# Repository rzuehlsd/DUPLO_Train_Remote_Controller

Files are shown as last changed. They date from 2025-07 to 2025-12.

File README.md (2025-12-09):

# DUPLO Train Remote Controller System

**A event-driven train remote control system for LEGO DUPLO, built on ESP32, FreeRTOS, and Bluetooth Low Energy (BLE).**

Copyright (c) 2022-2025 Ralf Zühlsdorff

This project is licensed under the terms of the MIT License. See the License section below for details.

----
## Table of Contents

- [DUPLO Train Remote Controller System](#duplo-train-remote-controller-system)
  - [Table of Contents](#table-of-contents)
  - [Project Overview](#project-overview)
  - [User Interface](#user-interface)
    - [Quick Start: Connecting a DUPLO Train](#quick-start-connecting-a-duplo-train)
    - [Button \& Encoder Actions](#button--encoder-actions)
    - [Optical Feedback (Controller RGB LED)](#optical-feedback-controller-rgb-led)
    - [Implemented Sensor Callbacks](#implemented-sensor-callbacks)
    - [Auto-Sleep \& Wake-Up](#auto-sleep--wake-up)
  - [Architecture Overview](#architecture-overview)
    - [Dual-Core Strategy](#dual-core-strategy)
    - [Future Improvements](#future-improvements)
  - [System Architecture](#system-architecture)
    - [Multi-Task Processing with Bidirectional Communication](#multi-task-processing-with-bidirectional-communication)
    - [Three-Layer Architecture](#three-layer-architecture)
    - [duploHub.init() Bootstrapping Flow](#duplohubinit-bootstrapping-flow)
  - [Features](#features)
  - [Hardware Requirements](#hardware-requirements)
    - [Primary Hardware](#primary-hardware)
    - [Supported LEGO Hardware](#supported-lego-hardware)
    - [Technical Specifications](#technical-specifications)
  - [Hardware Design](#hardware-design)
  - [Software Dependencies](#software-dependencies)
    - [Platform](#platform)
    - [Libraries](#libraries)
    - [Library Versions](#library-versions)
  - [Installation](#installation)
    - [1. Environment Setup](#1-environment-setup)
    - [2. Project Build \& Upload](#2-project-build--upload)
    - [3. Hardware Setup](#3-hardware-setup)
  - [Usage](#usage)
    - [Basic Operation](#basic-operation)
    - [Expected Serial Debug Output](#expected-serial-debug-output)
  - [API Reference](#api-reference)
    - [DuploHub Class](#duplohub-class)
      - [Connection Management](#connection-management)
      - [Control Methods (Thread-Safe)](#control-methods-thread-safe)
      - [Information Methods](#information-methods)
      - [Event Callbacks](#event-callbacks)
    - [DuploHubExtended Class (Sensor Support)](#duplohubextended-class-sensor-support)
      - [Sensor Callbacks](#sensor-callbacks)
      - [Sensor Activation (Thread-Safe)](#sensor-activation-thread-safe)
      - [Example Usage](#example-usage)
    - [Available Colors](#available-colors)
    - [Motor Speed Range](#motor-speed-range)
  - [System Monitoring](#system-monitoring)
    - [Status Information](#status-information)
    - [Log Message Prefixes](#log-message-prefixes)
  - [Troubleshooting](#troubleshooting)
    - [Common Issues \& Solutions](#common-issues--solutions)
      - [Connection Problems](#connection-problems)
      - [Task Failures](#task-failures)
      - [Command Delays](#command-delays)
    - [Debug Mode](#debug-mode)
  - [Development](#development)
    - [Project Structure](#project-structure)
    - [Adding New Features](#adding-new-features)
      - [New Train Commands](#new-train-commands)
      - [New Hub Types](#new-hub-types)
    - [Code Style Guidelines](#code-style-guidelines)
  - [Contributing](#contributing)
    - [Development Process](#development-process)
    - [Testing Checklist](#testing-checklist)
  - [Links](#links)
  - [License](#license)
  - [Acknowledgments](#acknowledgments)

---

## Project Overview

This project implements a robust, multi-layered, event-driven train controller for LEGO DUPLO trains. 

The system not only covers the firmware to controll the DUPLO train but also the required hardware and the OpenSCAD files for the case of the handheld controller.

I used a Tenstar Super Mini ESP32-S3 FH4R2 controller (yes, it is totally overkill for this application) because it provides onboard functionality as a RGB LED (used for user feedback) and a charging controller for a 3.7V Lithium battery. This onboard functionality reduced the required external components for the handheld controller to only 6 SMD switches, a rotary encoder and a few SMD resistors plus 1 capacitor.

The firmware builds on top of the open-source [Legoino](https://github.com/corneliusmunz/legoino) library created by Cornelius Munz, reusing its Powered Up protocol support while adding a hardened hardware abstraction tailored to ESP32 dual-core devices. Using both cores to implement the app signifficantly increased the overall reliability.

Key pillars of the solution include:

- **ESP32 dual-core architecture** (FreeRTOS): BLE communication runs independently from application logic for deterministic responsiveness.
- **Legoino-powered protocol stack**: Proven LEGO Powered Up discovery, device activation, and message parsing.
- **Thread-safe command and sensor queues**: Bidirectional, non-blocking communication between BLE and main application tasks.
- **Automatic connection management**: Self-healing BLE connections with exponential backoff recovery.
- **Enhanced logging and monitoring**: Real-time status, error, and performance reporting.
- **Deep Sleep and Wakeup**: In case no user interactions have been detected for more than 5 minutes the device goes to sleep and can be waked up by pressing the encoder button.

The high-level structure is summarised below; a deeper dive is available in [ARCHITECTURE.md](ARCHITECTURE.md).

## User Interface

THe handheld DUPLO train controller has 6 switches and a rotary encoder to send BLE commands to the DUPLO train hub. User feedback is provided through the onboard RGB LED of the ESP32-S3 controller.

### Quick Start: Connecting a DUPLO Train
- Power on the controller (ESP32) and the DUPLO Train Hub. 
- The DUPLO train will show a **white** blinking front light.
- The RGB LED of the controller turns to **yellow**.
- The controller immediately begins scanning for an active duplo train.
- Once internal initializatioon of the controller is completed the RBB LED turns to **green**. 
- If connected the DUPLO train will show a solid **blue** front light.
- After DUPLO train has connected, the controller’s RGB status LED turns to *blue** and blinks 3 times to confirm link.
- If no hub is found, the status LED pulses **orange** every few seconds to prompt you to power cycle or move the train closer.

### Button & Encoder Actions
- **Rotary encoder (turn):** Proportionally ramps the train motor between full reverse, neutral, and full forward with a tactile centre detent to simplify stops.
- **Rotary encoder (press):** Wakes the controller from deep sleep.
- **Record button:** Starts or stops capture of the current driving session, including speed, light, and sound changes for later replay.
- **Play button:** Replays the most recently recorded session, mirroring the captured timing for motor, LED, and audio cues. Press again to stop replay.
- **Stop button:** Issues an immediate emergency stop, cutting motor power and triggering the associated brake feedback sequence. To start normal operation the stop button **HAS TO BE PRESSED AGAIN**!
- **Light button:** Cycles through the preset DUPLO hub LED colours so the train can be themed without using a screen or app.
- **Sound button:** Steps through the curated horn, brake, and station audio effects for interactive play.
- **Water button:** Runs the refill routine, pausing the train, playing the refill sound, and resuming at the previous throttle setting.

### Optical Feedback (Controller RGB LED)
- **Blue (pulsing 5 times):** Connection to a DUPLO hub establish and ready for commands.
- **Red (slow blinking):** Recording action sequence.
- **Yellow (slow blinking):** Replaying action sequence.
- **Red (steady):** Emergency stop engaged. Goes off if button is engaged again
- **Red (fast pulses 5 times):** Signals low voltage of DUPLO train battery every 300 seconds

### Implemented Sensor Callbacks

The controller provides callback implementations for speed, voltage and color sensor events. While the speed sensor is currently not used, the voltage sensor gives warning feedback, if battery voltage of DUPLO Train drops below 5V.

The color sensor is used to detect the color bricks provided with the DUPLO train set to trigger preprogrammed actions. The detection of the correct colors is very tricky as it depends on the reflection of the color bricks. So expect some wrong colors to be detected. As we overwrite the preprogrammed actions here is a short description of the implemented actions:

- **RED** triggers a stop of the train with brake sound and red headlights
- **YELLOW** triggers departure of the train with yellow blinking headlights and horn sound
- **BLUE** triggers water refill action with blinking blue headlight, stop of train, water refill sound and departure of train with last defined speed

Currently all other colored bricks just set the headlight to the respective color.

### Auto-Sleep & Wake-Up
- After **5 minutes** without button presses or encoder turns, the controller enters deep sleep to save power; the status LED fades out to indicate standby.
- To reactivate, press the rotary encoder once to start initialization and connection cycle again

---
## Architecture Overview

The firmware is organised into three cooperating layers:

1. **Application Layer (`TrainController`)** – orchestrates user input, status LED feedback, replay/record logic, and system health checks.
2. **Hardware Abstraction Layer (`DuploHub`)** – maintains thread-safe command/response queues, sensors, and lifecycle management for the BLE task.
3. **Protocol Layer (`myLegoHub`/Legoino)** – bridges to the LEGO Powered Up protocol, handling device discovery and low-level message encoding.

These layers communicate exclusively through FreeRTOS queues and callbacks, which allows the BLE task and user interface to stay decoupled. The full architectural description, sequence diagrams, and performance considerations are documented in [ARCHITECTURE.md](ARCHITECTURE.md).

### Dual-Core Strategy

The ESP32’s two cores are used deliberately to isolate time-critical communication from user-driven workloads:

- **Core 0** is dedicated to the BLE stack (NimBLE) and the `DuploHub` task, guaranteeing consistent connection upkeep and sensor polling under tight timing constraints.
- **Core 1** runs the Arduino loop (`TrainController`), handling rotary encoder updates, button ladders, response queue processing, and visual/audible feedback without blocking the BLE stack.

This separation keeps latency predictable—even when the UI is busy—and prevents sensor interrupts or sound/LED routines from starving the communication pipeline.

### Future Improvements

- Function to pair with train (store ID and use when connecting)

---
## System Architecture

### Multi-Task Processing with Bidirectional Communication

```mermaid
graph LR
   MainTask["<b>Core 1 – Main Task</b><br/>• Application logic<br/>• User interface<br/>• Status display<br/>• Demo logic<br/>• Sensor processing<br/>• Event callbacks"]

   BleTask["<b>Core 0 – BLE Task</b><br/>• BLE operations<br/>• Hub connection<br/>• Motor commands<br/>• LED control<br/>• Sensor setup<br/>• Data parsing"]

   MainTask --> |CommandQueue| BleTask

   BleTask --> |SensorQueue| MainTask

   classDef queueStyle fill:#f2f2f2,stroke:#333,stroke-width:1px
   class CommandQueue,SensorQueue queueStyle
```

### Three-Layer Architecture

```mermaid
graph LR
   Layer1["<b>Layer 1: Application Layer</b><br/>• Train demo sequence &amp; state management<br/>• User interface &amp; status monitoring<br/>• High-level control logic<br/>• Connection event handling<br/>• Sensor data processing &amp; callbacks"]

   Layer2["<b>Layer 2: Hardware Abstraction</b><br/>• Thread-safe command queue<br/>• Bidirectional FreeRTOS queues<br/>• Multi-task management (dual-core ESP32)<br/>• Connection state management<br/>• Automatic recovery &amp; error handling<br/>• Sensor routing &amp; callback management"]

   Layer3["<b>Layer 3: Protocol Layer</b><br/>• LEGO Powered Up protocol<br/>• Bluetooth LE communication<br/>• Device discovery &amp; connection<br/>• Motor &amp; LED control commands<br/>• Sensor data parsing &amp; callbacks"]

   Layer1 -->|Clean API + sensor callbacks| Layer2
   Layer2 -->|Protocol interface + sensor integration| Layer3
```

### duploHub.init() Bootstrapping Flow

The following sequence diagram visualizes how the application brings up the BLE infrastructure when `duploHub.init()` is called from `TrainController::setup()`.

```mermaid
sequenceDiagram
   participant TC as TrainController::setup
   participant DH as DuploHub
   participant RTOS as FreeRTOS Scheduler
   participant BLE as BLE Task (Core 0)
   participant Lpf2 as Lpf2Hub

   TC->>DH: init()
   activate DH
   DH->>DH: initFreeRTOS()
   DH->>RTOS: xTaskCreatePinnedToCore(bleTaskWrapper)
   RTOS-->>DH: Task handle
   deactivate DH
   DH-->>TC: return

   RTOS->>BLE: schedule bleTaskWrapper(this)
   activate BLE
   BLE->>DH: bleTaskFunction()
   loop continuous loop
      BLE->>DH: updateBLE()
      alt Hub disconnected
         DH->>Lpf2: hub.init()
      else Hub connecting
         DH->>Lpf2: connectHub()
      end
      opt Connection state change
         DH-->>TC: onConnectedCallback()/onDisconnectedCallback()
      end
      BLE->>DH: processCommandQueue()
      DH->>Lpf2: Execute queued command
      BLE->>BLE: vTaskDelay(50 ms)
   end
```

---

## Features

- **Multi-Task BLE Management**: BLE operations run on a dedicated core, never blocking the main application.
- **Automatic Connection & Recovery**: Discovers, connects, and reconnects to DUPLO train hubs automatically.
- **Thread-Safe Commands**: Queue-based command system prevents race conditions.
- **Real-Time Control**: Low-latency motor speed and LED color control driven by rotary encoder input.
- **Sensor Integration**: Color, speed, and voltage sensors with callback support and queue isolation.
- **Color Stability Filtering**: Timer-based debounce suppresses transient color readings before they reach the UI.
- **Command Recording & Replay**: Capture user sessions and play them back with preserved timing.
- **Professional Logging**: Detailed, component-specific log messages and system status monitoring.
- **Idle Power Management**: Automatic deep sleep after configurable idle periods, resume via encoder button.
- **Resource Management**: Proper FreeRTOS object lifecycle management.
- **Input Abstraction**: ADC button ladder and rotary encoder handlers with debounced callbacks.
- **Demo Mode**: Non-blocking demo sequence with visual feedback and safety features.

---

## Hardware Requirements

### Primary Hardware

- **ESP32 Development Board ESP32-S3 Super Mini** (see link below)
    I use the Tenstar ESP32-S3 FH4R2 SuperMini which also includes cuircits to charge a 3.7V Lithium battery.
- **LEGO DUPLO Train Hub** with motor connected to Port A
- **USB Type C Cable** for programming and power

### Supported LEGO Hardware

- DUPLO Train Hub (Hub Type: `DUPLO_TRAIN_HUB`)
- DUPLO Train Motors (connected to Port A)
- Compatible with other Powered Up hubs (with minor modifications)

### Technical Specifications

- **Microcontroller**: ESP32 (dual-core, 240MHz)
- **Memory**: 520KB SRAM, 4MB Flash minimum
- **Connectivity**: Bluetooth 4.2 LE
- **Operating Voltage**: 3.3V
- **Power Consumption**: ~130mA during active BLE operation

---

## Hardware Design

The following images show the KiCAD 3d view of the controller pcb and the OpenSCAD view of the controller case. To design the controller case the MachineBlocks library from pks5 (https://github.com/pks5/machineblocks) has been used.

<p align="center">
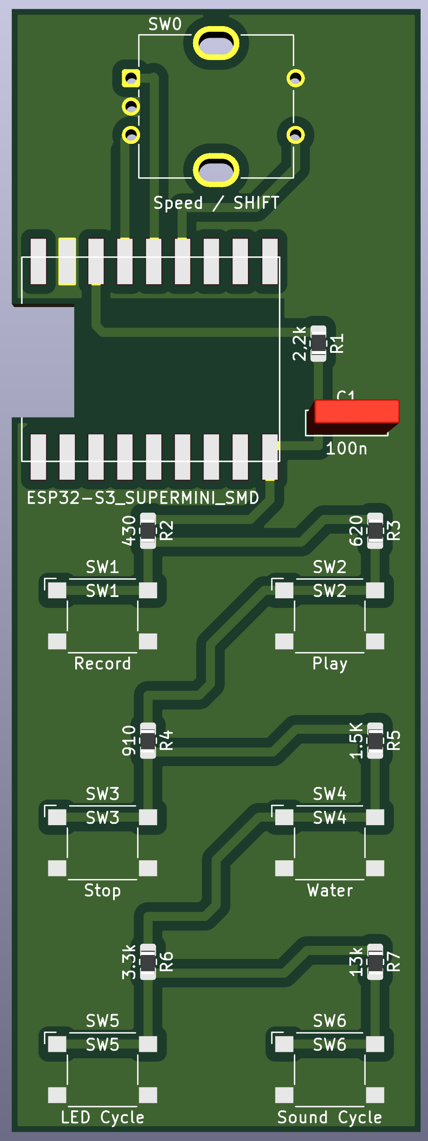
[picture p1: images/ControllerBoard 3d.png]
Controller board 3D render
    
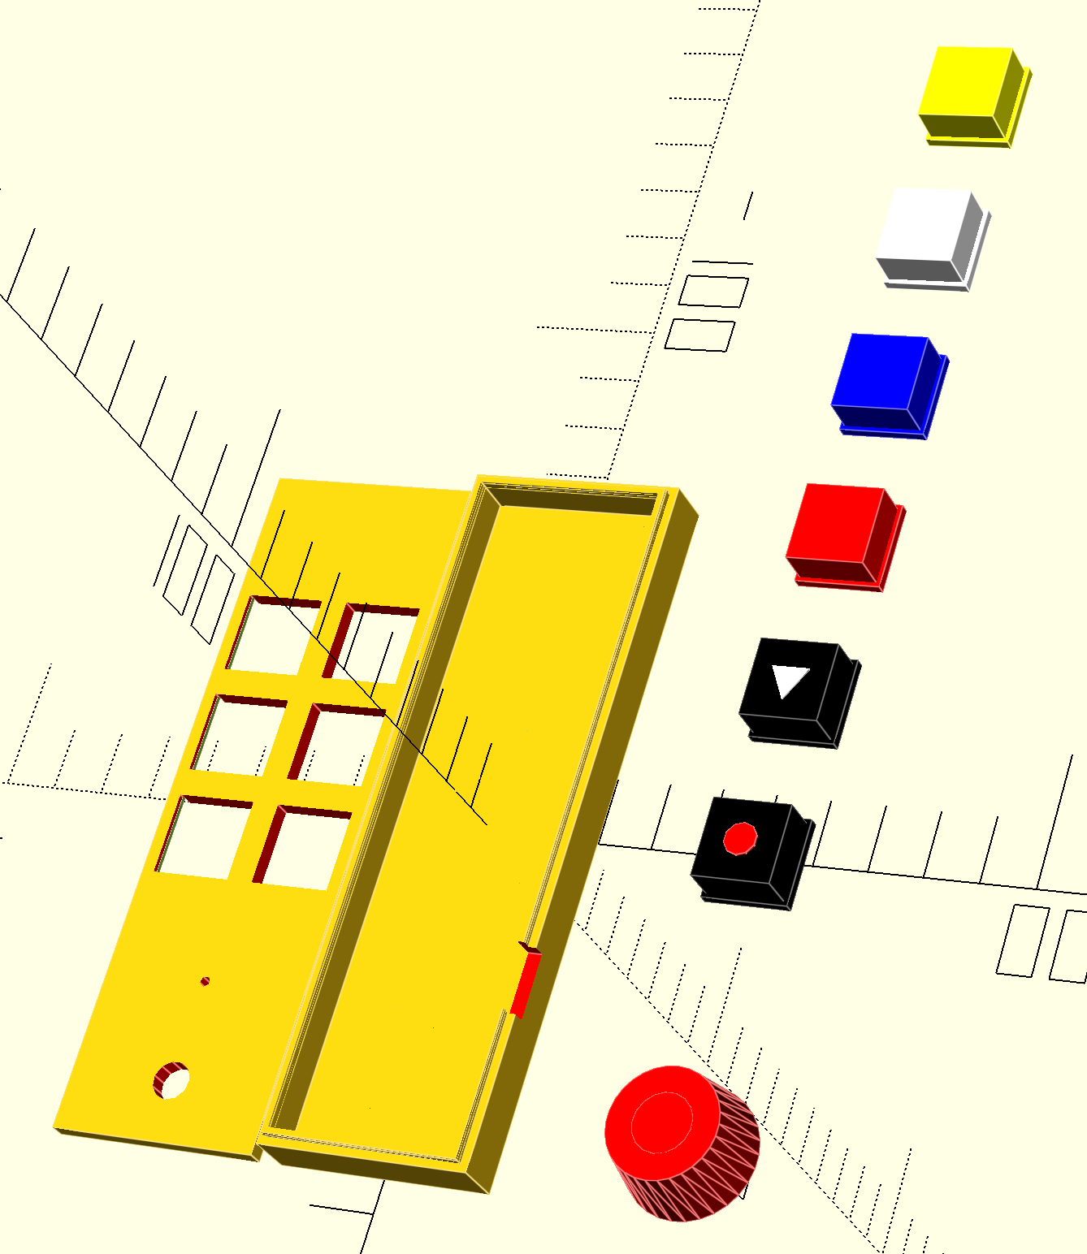
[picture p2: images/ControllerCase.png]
Controller case
    
</p>

- A dedicated ESP32-S3 carrier board with battery management and button/encoder headers is captured in KiCad inside `hardware/DuploTrainController NG`.
- A matching printable enclosure is modelled in OpenSCAD in `hardware/Case`, which also embeds the MachineBlocks library to speed up iteration on DUPLO-sized parts.

See [hardware/Hardware.md](hardware/Hardware.md) for a detailed description of the custom controller hardware.

## Software Dependencies

### Platform
- **PlatformIO**: Development platform
- **ESP32 Arduino Framework**: Core ESP32 support
- **FreeRTOS**: Real-time operating system (included with ESP32)

### Libraries

- **Legoino**: LEGO Powered Up protocol implementation by Cornelius Munz
- **NimBLE-Arduino**: Bluetooth Low Energy stack

All other libs used are provided as source in include and src dir.

### Library Versions

```ini
[env:esp32dev]
platform = espressif32
board = esp32dev
framework = arduino
lib_deps = 
    legoino/Legoino
    h2zero/NimBLE-Arduino
```

---

## Installation

Th development of this code has been done with MS Studio Code and PlatformIO.

### 1. Environment Setup

```bash
# Install PlatformIO CLI
pip install platformio

# Clone the repository
git clone <repository-url>
cd DuploTrain
```

### 2. Project Build & Upload

```bash
# Build the project
pio run

# Upload to ESP32
pio run --target upload

# Open serial monitor
pio device monitor
```

### 3. Hardware Setup

1. Connect ESP32 to computer via USB
2. Power on your DUPLO train hub
3. Ensure motor is connected to Port A of the hub
4. Upload and run the code

---

## Usage

### Basic Operation

1. **Startup**: System automatically starts and begins scanning for DUPLO hubs
2. **Connection**: When hub is found, automatic connection is established
3. **Demo**: Once connected, the demo sequence begins automatically
4. **Monitoring**: Status information is displayed every 10 seconds

### Expected Serial Debug Output

```text
TrainController: Starting up...
DuploHub: FreeRTOS objects initialized
DuploHub: BLE task started successfully
TrainController: Ready - BLE task running, waiting for hub connection...
BLE Task: Started successfully
BLE Task: Attempting initial connection to hub...
BLE Task: Connected to HUB
TrainController: Hub connected - initializing train demo!
TrainController: Starting train demo sequence...
TrainController Status - BLE Task: Running, Hub Connected: Yes, Demo Active: Yes
```

---

## API Reference

### DuploHub Class

#### Connection Management

```cpp
void startBLETask();                    // Start background BLE task
void stopBLETask();                     // Stop background BLE task
bool isConnected();                     // Check connection status (thread-safe)
bool isConnecting();                    // Check if connecting (thread-safe)
bool isDisconnected();                  // Check if disconnected (thread-safe)
bool isBLETaskRunning();                // Check BLE task status
```

#### Control Methods (Thread-Safe)

```cpp
void setMotorSpeed(int speed);          // Set motor speed (-100 to 100)
void stopMotor();                       // Stop motor immediately
void setLedColor(Color color);          // Set hub LED color
void setHubName(const char* name);      // Set hub name
```

#### Information Methods

```cpp
std::string getHubAddress();            // Get hub BLE address
std::string getHubName();               // Get hub name
byte getMotorPort();                    // Get configured motor port
void setMotorPort(byte port);           // Set motor port
```

#### Event Callbacks

```cpp
void setOnConnectedCallback(ConnectionCallback callback);     // Hub connected event
void setOnDisconnectedCallback(ConnectionCallback callback);  // Hub disconnected event
```

### DuploHubExtended Class (Sensor Support)

#### Sensor Callbacks

```cpp
typedef void (*ColorSensorCallback)(int color, byte port);
typedef void (*DistanceSensorCallback)(int distance, byte port);
typedef void (*ButtonCallback)(ButtonState state);

void setOnColorSensorCallback(ColorSensorCallback callback);      // Color sensor events
void setOnDistanceSensorCallback(DistanceSensorCallback callback);  // Distance sensor events
void setOnButtonCallback(ButtonCallback callback);                 // Button press events
```

#### Sensor Activation (Thread-Safe)

```cpp
void activateColorSensor(byte port);      // Activate color sensor on specified port
void activateDistanceSensor(byte port);   // Activate distance sensor on specified port
void activateButton();                    // Activate hub button monitoring
```

#### Example Usage

```cpp
// Color-based speed control
void onColorDetected(int color, byte port) {
    if (color == (byte)Color::RED) {
        duploHub.stopMotor();           // Emergency stop
    } else if (color == (byte)Color::GREEN) {
        duploHub.setMotorSpeed(50);     // Fast speed
    }
    duploHub.setLedColor((Color)color); // Match LED to detected color
}

// Setup
DuploHubExtended duploHub;
duploHub.setOnColorSensorCallback(onColorDetected);
duploHub.activateColorSensor((byte)PoweredUpHubPort::B);
```

### Available Colors

```cpp
BLACK, PINK, PURPLE, BLUE, LIGHTBLUE, CYAN, GREEN, YELLOW, ORANGE, RED, WHITE
```

### Motor Speed Range

- **Range**: -100 to 100
- **Positive**: Forward direction
- **Negative**: Backward direction
- **Zero**: Stop (equivalent to `stopMotor()`)

---

## System Monitoring

- **BLE Task**: Runs on Core 0, Priority 2
- **Main Loop**: Runs on Core 1, Priority 1
- **Connection Checks**: Every 1 second
- **Command Processing**: Every 50ms
- **Status Updates**: Every 10 seconds

### Status Information

The system provides comprehensive monitoring through serial output:

```text
TrainController Status - BLE Task: Running, Hub Connected: Yes, Demo Active: Yes
```

### Log Message Prefixes

- **`TrainController:`** - Main application messages
- **`BLE Task:`** - Background BLE task messages  
- **`DuploHub:`** - Hardware abstraction layer messages
- **`ERROR:`** - Critical system errors
- **`WARNING:`** - Non-critical issues

---

## Troubleshooting

### Common Issues & Solutions

#### Connection Problems
- Ensure DUPLO hub is powered on and in pairing mode
- Check if hub is already connected to another device
- Reset hub by holding button for 10 seconds
- Move ESP32 closer to hub (within 5 meters)

#### Task Failures
- Check available heap memory: `ESP.getFreeHeap()`
- Reduce other running tasks
- Increase stack size in `startBLETask()`

#### Command Delays
- Check command queue status
- Verify BLE connection stability
- Reduce command frequency in application

### Debug Mode

Enable detailed debugging by adding to `platformio.ini`:

```ini
build_flags = -DCORE_DEBUG_LEVEL=4
monitor_filters = esp32_exception_decoder
```

---

## Development

### Project Structure

```text
DuploTrain NG/
├── hardware/
│   ├── Case/
│   │   ├── Controller.scad
│   │   ├── MachineBlocks/
│   │   └── lib/
│   ├── DuploTrainController NG/
│   │   ├── DuploTrainController NG.kicad_pcb
│   │   ├── DuploTrainController NG.kicad_sch
│   │   ├── DuploTrainController NG.kicad_pro
│   │   ├── DuploTrainController NG.kicad_prl
│   │   ├── DuploTrainController NG.kicad_pcb.zip
│   │   ├── 5 Buttons an ADC.xlsx
│   │   └── Gerber/
│   └── README.md
├── include/
│   ├── ADCButton.h
│   ├── DuploHub.h
│   ├── StatusLED.h
│   ├── SystemMemory.h
│   ├── debug.h
│   └── myLegoHub.h
├── lib/
│   ├── Legoino/
│   └── NimBLE-Arduino/
├── src/
│   ├── ADCButton.cpp
│   ├── DuploHub.cpp
│   ├── StatusLED.cpp
│   ├── SytemMemory.cpp
│   ├── TrainController.cpp
│   ├── debug.cpp
│   └── myLegoHub.cpp
├── test/
│   ├── DuploTrainTests.cpp
│   ├── DuploTrainTests.h
│   └── README.md
├── ARCHITECTURE.md
├── CHANGELOG.md
├── platformio.ini
└── README.md
```

### Adding New Features

#### New Train Commands
1. Add command type to `CommandType` enum in `DuploHub.h`
2. Add command data structure to `HubCommand` union
3. Implement thread-safe method in `DuploHub` class
4. Add processing logic to `processCommandQueue()`

#### New Hub Types
1. Modify hub type detection in BLE scanning
2. Add hub-specific command handling
3. Update motor port configurations if needed

### Code Style Guidelines
- Use clear, descriptive variable names
- Add comprehensive comments for complex logic
- Follow Arduino coding standards
- Use thread-safe practices for shared data
- Include error handling for all operations

---

## Contributing

### Development Process
1. Fork the repository
2. Create feature branch (`git checkout -b feature/new-feature`)
3. Follow code style guidelines
4. Add comprehensive comments
5. Test thoroughly on hardware
6. Submit pull request with detailed description

### Testing Checklist
- [ ] Builds without warnings
- [ ] Connects to DUPLO hub successfully
- [ ] Motor control works in both directions
- [ ] LED colors change correctly
- [ ] Reconnection works after power cycle
- [ ] No memory leaks during long operation
- [ ] Task monitoring shows healthy system

---

## Links

- [ESP32 Super Mini](https://de.aliexpress.com/item/1005010463397231.html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)
- [Lithium Battery 3.7V](https://de.aliexpress.com/item/1005004378108918.html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,scm-url:1007.14452.478275.0,pvid:03756532-275c-4ab9-bd8a-2053af674cb4,tpp_buckets:668%232846%238108%231977&pdp_ext_f=%7B%22order%22%3A%2247%22%2C%22eval%22%3A%221%22%2C%22sceneId%22%3A%2230050%22%2C%22fromPage%22%3A%22recommend%22%7D&pdp_npi=6%40dis%21EUR%215.68%214.09%21%21%216.46%214.65%21%4021038e6617651853991155852e878e%2112000028967861661%21rec%21DE%216288981052%21X%211%210%21n_tag%3A-29919%3Bd%3A6804e1a2%3Bm03_new_user%3A-29895&utparam-url=scene%3ApcDetailTopMoreOtherSeller%7Cquery_from%3A%7Cx_object_id%3A1005004378108918%7C_p_origin_prod%3A&search_p4p_id=202512080116391515856091447492685637_4)
- [MachineBlocks](https://github.com/pks5/machineblocks)
---

## License

MIT License

Permission is hereby granted, free of charge, to any person obtaining a copy
of this software and associated documentation files (the "Software"), to deal
in the Software without restriction, including without limitation the rights
to use, copy, modify, merge, publish, distribute, sublicense, and/or sell
copies of the Software, and to permit persons to whom the Software is
furnished to do so, subject to the following conditions:

The above copyright notice and this permission notice shall be included in all
copies or substantial portions of the Software.

THE SOFTWARE IS PROVIDED "AS IS", WITHOUT WARRANTY OF ANY KIND, EXPRESS OR
IMPLIED, INCLUDING BUT NOT LIMITED TO THE WARRANTIES OF MERCHANTABILITY,
FITNESS FOR A PARTICULAR PURPOSE AND NONINFRINGEMENT. IN NO EVENT SHALL THE
AUTHORS OR COPYRIGHT HOLDERS BE LIABLE FOR ANY CLAIM, DAMAGES OR OTHER
LIABILITY, WHETHER IN AN ACTION OF CONTRACT, TORT OR OTHERWISE, ARISING FROM,
OUT OF OR IN CONNECTION WITH THE SOFTWARE OR THE USE OR OTHER DEALINGS IN THE
SOFTWARE.

---

## Acknowledgments

- **Cornelius Munz** - Legoino library creator
- **LEGO Group** - DUPLO and Powered Up hardware
- **Espressif** - ESP32 platform
- **Arduino Community** - Framework and libraries

---

**Version:** 2.0.0  
**Last Updated:** July 2025  
**Compatibility:** ESP32, Arduino Framework, PlatformIO

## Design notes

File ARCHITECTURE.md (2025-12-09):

# Technical Architecture Document

**Author:** Ralf Zühlsdorff  
**Copyright:** (c) 2025 Ralf Zühlsdorff  
**License:** MIT License

---

## System Overview

The DUPLO Train Controller implements a robust, modular, event-driven architecture for LEGO train control, optimized for ESP32 dual-core systems. It extends the [Legoino](https://github.com/JorgePe/legoino) library by Jorge Pereira, adding hardened FreeRTOS primitives, queue-based communication, and application-level automation tailored to ESP32 hardware capabilities. The design leverages thread-safe queues and static callback wrappers to ensure reliable BLE communication, real-time sensor feedback, and responsive user control.

Key runtime capabilities include:

- Dual-core scheduling that dedicates Core 0 to BLE and sensor handling while Core 1 processes user interaction and replay automation.
- A color stability timer that debounces rapid sensor transitions before events reach the UI layer.

## Multi-Task Architecture

```
ESP32 Core 0 (Protocol Core)        ESP32 Core 1 (Application Core)
├── BLE Stack (NimBLE)              ├── Arduino Main Loop
├── BLE Task (DuploHub)             ├── TrainController Logic
├── FreeRTOS Scheduler              ├── Demo State Machine
└── Hardware Interrupts             └── User Callbacks
```

| Task | Core | Priority | Stack Size | Timing |
|---|---|---|---|---|
| Arduino Loop | 1 | 1 | 8KB | Continuous |
| BLE Task | 0 | 2 | 4KB | 50ms cycle |
| Idle Tasks | Both | 0 | 1KB | As needed |
```cpp

class DuploHub {
private:
    SemaphoreHandle_t connectionMutex;    // Protects connection state
    QueueHandle_t commandQueue;           // Main → BLE task commands
    QueueHandle_t responseQueue;          // BLE task → Main responses/events
    TaskHandle_t bleTaskHandle;           // BLE task lifecycle
    volatile bool connectionState;        // Atomic state variables
    volatile bool connectingState;
};
```

### Critical Sections

```cpp

// Example: Thread-safe connection state access
bool DuploHub::isConnected() {
    if (connectionMutex != nullptr) {
        xSemaphoreTake(connectionMutex, portMAX_DELAY);
        bool state = connectionState;
        xSemaphoreGive(connectionMutex);
        return state;
    }
    return hub.isConnected(); // Fallback if mutex not initialized
}
```

### Command Queue Protocol

```cpp

// Command structure for inter-task communication
typedef struct {
    CommandType type;           // Command identifier
    union {
        struct { int speed; } motor;
        struct { Color color; } led;
        struct { char name[32]; } hubName;
        // ... other command types ...
    } data;
} HubCommand;

// Response structure for BLE → Main communication
typedef struct {
    ResponseType type;          // Response identifier (e.g., Detected_Color, Detected_Speed)
    union {
        struct { int detectedColor; } colorResponse;
        struct { int detectedSpeed; } speedResponse;
        struct { float detectedVoltage; } voltageResponse;
        // ... other response types ...
    } data;
} HubResponse;
```

## Memory Management

### Static Allocation Strategy
- **Command Queue**: 10 × `sizeof(HubCommand)` = ~320 bytes
- **Task Stacks**: BLE Task (4KB), Main Loop (8KB)
- **Synchronization Objects**: ~100 bytes total
- **String Buffers**: Fixed-size arrays for thread safety

### Heap Usage Optimization
- Minimal dynamic allocation
- String operations use stack buffers
- BLE operations handled by NimBLE stack
- No memory leaks in main application code

## Communication Flow

### Startup Sequence

```mermaid
sequenceDiagram
    participant App as TrainController
    participant Hub as DuploHub
    participant BLE as BLE Task
    participant LEGO as Lpf2Hub

    App->>Hub: Constructor (initFreeRTOS)
    Hub->>Hub: Create Mutex & Queue
    App->>Hub: startBLETask()
    Hub->>BLE: Create Task (Core 0)
    BLE->>LEGO: hub.init() - Start scanning
    LEGO-->>BLE: Device found callback
    BLE->>LEGO: hub.connectHub()
    BLE->>Hub: updateConnectionState(true)
    Hub->>App: onConnectedCallback()
```

### Command Execution Flow

```mermaid
sequenceDiagram
    participant App as TrainController
    participant Queue as Command Queue
    participant BLE as BLE Task
    participant LEGO as Lpf2Hub

    App->>Queue: setMotorSpeed(50)
    Queue-->>BLE: Command available
    BLE->>Queue: Dequeue command
    BLE->>LEGO: setBasicMotorSpeed(port, 50)
    LEGO-->>BLE: BLE transmission complete
```

## Error Handling Strategy

### Failure Recovery Mechanisms

1. **BLE Task Monitoring**: Main loop checks task health every 5 seconds
2. **Connection Recovery**: Automatic reconnection with exponential backoff
3. **Command Queue Overflow**: Non-blocking queue operations with warnings
4. **Resource Cleanup**: Proper destruction in destructors and error paths

### Error Categories

| Category | Handling | Recovery |
|---|---|---|
| BLE Connection Loss | Automatic retry | Background reconnection |
| Task Creation Failure | Error logging | Fallback to synchronous mode |
| Queue Full | Drop command + warning | Continue operation |
| Memory Allocation | Error logging | Graceful degradation |

## Performance Characteristics

### Latency Analysis

| Operation | Typical Latency | Maximum Latency |
|---|---|---|
| Motor Command | 50-100ms | 200ms |
| LED Command | 30-80ms | 150ms |
| Connection Detection | 1-3 seconds | 10 seconds |
| State Query | <1ms | 5ms (mutex wait) |

### Throughput Capabilities

- **Command Rate**: ~20 commands/second sustainable
- **BLE Bandwidth**: ~1KB/second LEGO protocol data
- **CPU Utilization**: ~15% Core 0, ~5% Core 1 during active operation

## Bidirectional Sensor Data Architecture

### Queue Model

The firmware relies on two FreeRTOS queues to decouple the BLE task from the application loop:

```mermaid
flowchart LR
    subgraph Core1["Main Loop (Core 1)"]
        TC["TrainController::loop<br/>• Rotary & buttons<br/>• processResponseQueue<br/>• record / replay"]
    end

    subgraph Core0["BLE Task (Core 0)"]
        BLE["DuploHub::bleTaskFunction<br/>• hub.connectHub()<br/>• processCommandQueue<br/>• static callbacks"]
    end

    CommandQueue["commandQueue<br/>(10 items)"]:::queue
    ResponseQueue["responseQueue<br/>(100 items)"]:::queue

    TC -->|commands| CommandQueue -->|dispatch| BLE
    BLE -->|responses| ResponseQueue -->|process| TC

    classDef queue fill:#f2f2f2,stroke:#555,stroke-width:1px;
```

- `commandQueue` carries `HubCommand` objects from the application to the BLE task (motor, sound, LED, sensor activation, name changes). Each command includes a timestamp so the recorder can normalise playback timing.
- `responseQueue` returns `HubResponse` objects (colour, speed, voltage updates) from the BLE task to the application. The queue depth of 100 entries absorbs bursts from the colour sensor while the UI performs other work.

### Color Stability Timer

Rapid color transitions generated by the DUPLO sensor are filtered by a one-shot `esp_timer` that fires after 250 ms of stability. The timer is created lazily by `ensureColorTimerInitialized()` and shared across callbacks via a `portMUX_TYPE` critical section. The timer callback:

1. Compares the pending colour against the last stable value.
2. Enqueues a `HubResponse` only when the reading truly changes.
3. Resets the pending colour so the next sensor event will re-arm the timer.

This approach lowers noise in the response queue without blocking the BLE task, and keeps user automation deterministic.

### Command & Event Flow

1. **Command path (Main → BLE)**
   ```cpp
   HubCommand cmd = {...};
   sendCommand(cmd, pdMS_TO_TICKS(100));   // TrainController → DuploHub
   // BLE task dequeues the command and forwards it via Legoino APIs
   ```

2. **Sensor path (BLE → Main)**
   ```cpp
   staticColorSensorCallback(...)  // BLE context
     ↳ ensureColorTimerInitialized()
     ↳ esp_timer_start_once()

   colorStabilityTimerCallback(...)
     ↳ HubResponse response{Detected_Color, ...};
     ↳ xQueueSend(responseQueue, ...);

   TrainController::processResponseQueue()
     ↳ switch(response.type) { ... detectedColorCb(...) ... }
   ```

3. **Record / Replay integration**
   - When recording is enabled, every outbound `HubCommand` is copied into `commandBuffer` together with its timestamp.
   - `replayCommands()` normalises timestamps and replays through `sendCommand()` while the main loop checks `getNextReplayCommand()` to maintain timing.

### Memory Usage Snapshot

| Queue | Direction | Capacity | Approx. item size | Purpose |
|---|---|---|---|---|
| `commandQueue` | Main → BLE | 10 items | ~48 B (`HubCommand`) | Motor, LED, sound, sensor activation, hub name |
| `responseQueue` | BLE → Main | 100 items | ~16 B (`HubResponse`) | Colour, speed, voltage notifications |

Additional shared resources include the connection mutex (~92 B), the BLE task stack (4 KB), and the colour stability timer (control block provided by ESP timer service).

### Extending `HubCommand` / `HubResponse`

New device capabilities can be exposed by adding enum values and union members in `include/DuploHub.h`. The queue infrastructure already supports arbitrary payloads as long as the structs remain POD types.

### Multiple Hub Support

Managing several train hubs simply requires instantiating multiple `DuploHub` objects—each one provisions its own command/response queues, timer handle, and BLE task instance.

## Debug and Monitoring Infrastructure

### Logging and Debugging

The system uses a mutex-protected debug logging macro (`DEBUG_LOG`) for thread-safe output from both main and BLE tasks. Logging levels can be adjusted for error, warning, info, and debug output.

### Runtime Statistics

System monitoring functions (e.g., `printMemoryInfo()`) are available to report free heap, BLE task stack usage, and queue status for debugging and performance analysis.

## Security Considerations

### BLE Security
- No pairing/bonding implemented (LEGO hubs don't require it)
- Connection based on service UUID matching
- Limited to LEGO protocol commands only

### Code Security
- No dynamic code execution
- Fixed-size buffers prevent overflows
- Input validation on all external data

## Documentation and Code Quality

All major classes and functions are documented using Doxygen-style comments, including parameter and return value descriptions. Each file includes author, copyright, and the full MIT license.

**Future Enhancement Opportunities:**

1. **Sensor Integration**: Support for LEGO speed sensor
2. **Multiple Trains**: Coordinate multiple train hubs, e.g. pinning controller to specific train

## Complete Sensor Processing Chain Analysis

This section provides a complete trace of how a sensor value (e.g., color detection) flows through all layers of the architecture, from physical hardware to application callback.

### **Layer 1: Physical Hardware → BLE Radio**
```
DUPLO Color Sensor Hardware
├── Detects color change (e.g., RED)
├── Generates sensor data packet
└── Transmits via BLE to ESP32
```
- **📍 Location**: DUPLO train hub hardware  
- **📝 Data Format**: Raw BLE characteristic update with color data
- **⏱️ Timing**: Immediate hardware response to color change

### **Layer 2: ESP32 BLE Stack → NimBLE Library**
```cpp
// NimBLE Arduino Library (Core 0)
// Receives BLE characteristic notification
// Parses BLE packet and routes to registered callback
```
- **📍 Running on**: Core 0 (BLE task context)  
- **📝 Data Format**: Parsed BLE packet with device type and raw sensor bytes
- **⏱️ Timing**: ~5-10ms BLE packet processing

### **Layer 3: Lpf2Hub Library Callback**
```cpp
// File: Legoino/src/Lpf2Hub.cpp
// Internal Lpf2Hub processing - calls registered device callback
void Lpf2Hub::notifyCallback(NimBLERemoteCharacteristic* pChar, uint8_t* pData, size_t length) {
    // ... BLE packet parsing ...
    
    // Calls our registered callback for the port
    if (_portDeviceCallback[portNumber] != nullptr) {
        _portDeviceCallback[portNumber](this, portNumber, deviceType, pData);
        //                                ↑ This calls our wrapper function
    }
}
```
- **📍 Running on**: Core 0 (BLE task context)  
- **📝 Purpose**: LEGO Powered Up protocol parsing and routing
- **⏱️ Timing**: ~2-5ms protocol parsing

### **Layer 4: DuploHub Static Callback Wrapper**
```cpp
void DuploHub::staticColorSensorCallback(void *hub,
                                         byte portNumber,
                                         DeviceType deviceType,
                                         uint8_t *pData) {
    myLegoHub *myHub = static_cast<myLegoHub *>(hub);
    (void)portNumber;

    if (deviceType != DeviceType::DUPLO_TRAIN_BASE_COLOR_SENSOR) {
        return;
    }

    int detectedColor = myHub->parseColor(pData);
    if (detectedColor < DuploEnums::DuploColor::BLACK ||
        detectedColor > DuploEnums::DuploColor::WHITE) {
        return; // Ignore out-of-range values entirely
    }

    if (!ensureColorTimerInitialized()) {
        HubResponse response{};
        response.type = Detected_Color;
        response.data.colorResponse.detectedColor = static_cast<DuploEnums::DuploColor>(detectedColor);
        xQueueSend(instance->responseQueue, &response, pdMS_TO_TICKS(100));
        return;
    }

    bool restartTimer = false;

    portENTER_CRITICAL(&colorTimerMutex);
    if (pendingColor != detectedColor) {
        pendingColor = detectedColor;
        restartTimer = true;
    } else if (!esp_timer_is_active(colorStabilityTimer)) {
        restartTimer = true;
    }
    portEXIT_CRITICAL(&colorTimerMutex);

    if (restartTimer) {
        esp_timer_stop(colorStabilityTimer);
        esp_timer_start_once(colorStabilityTimer, COLOR_SETTLE_DELAY_US);
    }
}
```
- **📍 Running on**: Core 0 (BLE task context)
- **🔧 Key Operations**: Parses raw Legoino payloads, primes the debounce timer, and falls back to immediate queueing if the timer handle is unavailable.

### **Layer 5: Colour Stability Timer Callback**
```cpp
void DuploHub::colorStabilityTimerCallback(void *arg) {
    (void)arg;
    int colorToEmit = -1;

    portENTER_CRITICAL(&colorTimerMutex);
    if (pendingColor >= DuploEnums::DuploColor::BLACK &&
        pendingColor <= DuploEnums::DuploColor::WHITE) {
        if (pendingColor != lastStableColor) {
            colorToEmit = pendingColor;
            lastStableColor = pendingColor;
        }
    }
    pendingColor = -1;
    portEXIT_CRITICAL(&colorTimerMutex);

    if (colorToEmit == -1) {
        return; // Nothing new to report
    }

    HubResponse response{};
    response.type = Detected_Color;
    response.data.colorResponse.detectedColor = static_cast<DuploEnums::DuploColor>(colorToEmit);
    xQueueSend(instance->responseQueue, &response, pdMS_TO_TICKS(100));
}
```
- **📍 Running on**: ESP timer service (Core 0 context)
- **🔧 Key Operations**: Stable-colour detection, queueing of colour events, deduplication of unchanged values.

### **Layer 6: TrainController Response Processing**
```cpp
void DuploHub::processResponseQueue() {
    if (responseQueue == nullptr) {
        return;
    }

    HubResponse response;
    while (xQueueReceive(responseQueue, &response, 0) == pdTRUE) {
        switch (response.type) {
            case Detected_Color:
                if (detectedColorCallback != nullptr) {
                    detectedColorCallback(response.data.colorResponse.detectedColor);
                }
                break;
            case Detected_Speed:
                if (detectedSpeedCallback != nullptr) {
                    detectedSpeedCallback(response.data.speedResponse.detectedSpeed);
                }
                break;
            case Detected_Voltage:
                if (detectedVoltageCallback != nullptr) {
                    detectedVoltageCallback(response.data.voltageResponse.detectedVoltage);
                }
                break;
        }
    }
}
```
- **📍 Running on**: Core 1 (main application loop)
- **🔧 Key Operations**: Non-blocking dequeue until empty, invocation of application callbacks.

### **Layer 7: TrainController Application Logic**
```cpp
static void detectedColorCb(DuploEnums::DuploColor color) {
    if (replay) {
        DEBUG_LOG("TrainController: Color sensor callback ignored during replay");
        return;
    }

    DEBUG_LOG("TrainController:  Detected Color: %d", color);
    detectedColor = color;

    switch (color) {
        case DuploEnums::DuploColor::BLACK:
            duploHub.setLedColor(DuploEnums::DuploColor::BLACK);
            statusLed.setColor(CRGB::Black);
            delay(DELAY_TIME);
            break;
        case DuploEnums::DuploColor::RED:
            emergencyStop = !emergencyStop;
            statusLed.setColor(CRGB::Red);
            statusLed.setBlinking(true, 250, 250, 3);
            duploHub.playSound(DuploEnums::DuploSound::BRAKE);
            break;
        // Additional colour cases (YELLOW, BLUE, WHITE, etc.) follow the same pattern.
    }
}
```
- **📍 Running on**: Core 1 (main application loop)
- **🔧 Key Operations**: Applies rule-based automation (emergency stop toggling, sounds, motor/speed control, LED feedback) and updates user-visible state.

### **Layer 8: Application Callback (TrainController)**
```cpp
// File: src/TrainController_Extended.cpp - Line ~62
void onColorDetected(int color, byte port) {
    Serial.print("TrainController Extended: Color detected - ");
    Serial.print(LegoinoCommon::ColorStringFromColor(color).c_str());
    Serial.print(" on port ");
    Serial.println(port);
    
    lastDetectedColor = color;
    
    // Set LED to detected color
    duploHub.setLedColor((Color)color);
    
    // Control train based on color
    if (color == (byte)Color::RED) {
        Serial.println("TrainController Extended: RED detected - STOP");
        duploHub.stopMotor();  // ← This triggers another command queue operation
    } 
    else if (color == (byte)Color::GREEN) {
        Serial.println("TrainController Extended: GREEN detected - FAST (speed 50)");
        duploHub.setMotorSpeed(50);  // ← Command flows back Main → BLE via commandQueue
    }
    // ... other colors ...
}
```
- **📍 Running on**: Core 1 (Main task context)  
- **📝 Purpose**: Application-specific logic and train control decisions
- **🔧 Result**: Motor control commands are queued back to BLE task
- **⏱️ Timing**: User code execution time varies

### Complete Processing Timeline

```
┌─────────────────────────────────────────────────────────────────────────┐
│                        SENSOR PROCESSING TIMELINE                       │
├─────────────────────────────────────────────────────────────────────────┤
│                                                                         │
│ Time 0ms:   DUPLO sensor detects RED color                             │
│ Time 5ms:   BLE packet transmitted to ESP32                            │
│ Time 10ms:  NimBLE receives and parses BLE characteristic              │
│ Time 15ms:  DuploHub::staticColorSensorCallback stores candidate colour│
│ Time 20ms:  esp_timer_start_once arms 250 ms stability window          │
│ Time 265ms: colorStabilityTimerCallback enqueues stable colour         │
│ Time 270ms: TrainController::loop() drains duploHub.processResponseQueue│
│ Time 275ms: detectedColorCb() applies automation rules                 │
│ Time 280ms: duploHub.stopMotor() queued to commandQueue (if required)  │
│ Time 320ms: BLE task dequeues stop command and forwards to hub         │
│ Time 360ms: DUPLO train motor confirms stop                            │
│                                                                         │
│ TOTAL LATENCY: ~360ms from sensor detection to motor action            │
└─────────────────────────────────────────────────────────────────────────┘
```

### Processing Chain Benefits

#### **Thread Safety**
- ✅ **No shared memory**: All data passes through FreeRTOS queues
- ✅ **Atomic operations**: Queue operations are interrupt-safe
- ✅ **No race conditions**: Clear producer/consumer pattern

#### **Performance**
- ✅ **Non-blocking**: Main loop never waits for BLE operations
- ✅ **Deterministic debounce**: 250 ms timer filters noisy colour transitions
- ✅ **Predictable latency**: ~360 ms sensor-to-action including stability window

#### **Reliability**
- ✅ **Error handling**: Queue overflow detection and logging
- ✅ **Data integrity**: Timestamped sensor data with port information
- ✅ **Graceful degradation**: System continues if callbacks fail

#### **Scalability**
- ✅ **Multiple sensors**: Same pattern works for color, distance, button
- ✅ **Configurable queues**: Queue sizes can be adjusted for performance
- ✅ **Extensible**: Easy to add new sensor types and callbacks

## Complete Command Processing Chain Analysis

While the sensor processing flows BLE → Main, command processing flows in the opposite direction. Here's the complete analysis for a `setMotorSpeed(50)` command:

### **Layer 1: Application Command (TrainController)**
```cpp
// File: src/TrainController_Extended.cpp - Line ~75
void onColorDetected(int color, byte port) {
    // User application logic
    if (color == (byte)Color::GREEN) {
        duploHub.setMotorSpeed(50);  // ← This is where our analysis starts
    }
}
```
- **📍 Running on**: Core 1 (Main task - Arduino loop context)
- **📝 Purpose**: Application-level decision to change motor speed
- **⏱️ Timing**: Immediate function call

### **Layer 2: DuploHub Public API (Hardware Abstraction)**
```cpp
// File: include/DuploHub_Extended.h - Line ~108 (Legacy wrapper)
void setMotorSpeed(int speed) { setMotorSpeed_ThreadSafe(speed); }
```
- **📍 Running on**: Core 1 (Main task context)
- **📝 Purpose**: Backward compatibility wrapper - immediately calls thread-safe version
- **⏱️ Timing**: ~1µs function call overhead

### **Layer 3: DuploHub Protected Thread-Safe Implementation**
```cpp
// File: src/DuploHub_Extended.cpp - Line ~173 (from base DuploHub)
void DuploHub::setMotorSpeed_ThreadSafe(int speed) {
    if (commandQueue != nullptr) {
        HubCommand cmd;
        cmd.type = CMD_MOTOR_SPEED;
        cmd.data.motor.speed = speed;
        
        if (xQueueSend(commandQueue, &cmd, pdMS_TO_TICKS(100)) != pdTRUE) {
            Serial.println("WARNING: Failed to queue motor speed command");
        }
    } else {
        // Fallback to direct call if queue not initialized
        hub.setBasicMotorSpeed(motorPort, speed);
    }
}
```
- **📍 Running on**: Core 1 (Main task context)
- **📝 Purpose**: Thread-safe command packaging and queuing
- **🔧 Key Operations**:
  - Creates `HubCommand` struct with `CMD_MOTOR_SPEED` type
  - Packages speed value (50) into command data
  - Uses `xQueueSend()` to send to BLE task (100ms timeout)
- **⏱️ Timing**: ~1-3ms for struct creation and queue operation

### **Layer 4: FreeRTOS Command Queue (Inter-Core Communication)**
```
FreeRTOS Queue: commandQueue
- Queue Size: 10 commands
- Item Size: sizeof(HubCommand) ~40 bytes
- Timeout: 100ms (blocking if queue full)
- Direction: Core 1 → Core 0
```
- **📍 Location**: FreeRTOS kernel space
- **📝 Purpose**: Thread-safe communication between cores
- **🔧 Mechanism**: Command waits in queue until BLE task processes it
- **⏱️ Timing**: ~1ms queue operation + variable wait time

### **Layer 5: BLE Task Command Processing Loop**
```cpp
// File: src/DuploHub_Extended.cpp - Line ~290 (from base DuploHub)
void DuploHub::bleTaskFunction() {
    const unsigned long CONNECTION_CHECK_INTERVAL = 1000;
    
    while (true) {
        unsigned long currentTime = millis();
        
        if (currentTime - lastConnectionCheck >= CONNECTION_CHECK_INTERVAL) {
            updateBLE();
            lastConnectionCheck = currentTime;
        }
        
        // Process command queue more frequently for responsiveness
        processCommandQueue();  // ← Our command gets processed here
        
        vTaskDelay(pdMS_TO_TICKS(50)); // 50ms delay
    }
}
```
- **📍 Running on**: Core 0 (Dedicated BLE task)
- **📝 Purpose**: Background command processing with 50ms polling interval
- **⏱️ Timing**: Commands processed every 50ms maximum

### **Layer 6: Command Queue Dequeuing and Execution**
```cpp
// File: src/DuploHub.cpp - processCommandQueue()
void DuploHub::processCommandQueue()
{
    if (commandQueue == nullptr)
        return;

    HubCommand cmd;

    while (xQueueReceive(commandQueue, &cmd, 0) == pdTRUE)
    {
        if (!hub.isConnected())
        {
            DEBUG_LOG("BLE Task: Skipping command - hub not connected");
            continue;
        }

        switch (cmd.type)
        {
        case CommandType::CMD_MOTOR_SPEED:
            DEBUG_LOG("BLE Task: Setting motor speed to %d", cmd.data.motor.speed);
            hub.setBasicMotorSpeed((byte)DuploEnums::DuploTrainHubPort::MOTOR, cmd.data.motor.speed);
            delay(20);
            break;

        case CommandType::CMD_STOP_MOTOR:
            DEBUG_LOG("BLE Task: Stopping motor");
            hub.stopBasicMotor((byte)DuploEnums::DuploTrainHubPort::MOTOR);
            delay(20);
            break;

        case CommandType::CMD_SET_LED_COLOR:
            DEBUG_LOG("BLE Task: Setting LED color to %d", cmd.data.led.color);
            hub.setLedColor((Color)cmd.data.led.color);
            delay(200);
            break;

        // ... additional command handlers (rename hub, play sound, activate sensors) ...
        }
    }
}
```
- **📍 Running on**: Core 0 (BLE task context)
- **📝 Purpose**: Drain the command queue and forward actions to the Powered Up hub
- **🔧 Key Operations**:
  - Non-blocking `xQueueReceive` loop guarded by connection state checks
  - Dispatches to Legoino primitives with minimal inter-command delays
  - Handles LED, sound, sensor activation, and replay traffic uniformly
- **⏱️ Timing**: <2 ms per iteration plus command-specific BLE delays

### **Layer 7: Lpf2Hub Protocol Implementation**
```cpp
// From Legoino library - Lpf2Hub.cpp
hub.setBasicMotorSpeed(motorPort, cmd.data.motor.speed);
//                     Port A,    50

// Internal Lpf2Hub processing:
void Lpf2Hub::setBasicMotorSpeed(byte port, int speed) {
    // Convert speed to LEGO protocol format
    // Create BLE characteristic write command
    // Format: [Port][Command][Speed_Low][Speed_High]
    uint8_t setMotorCommand[] = {0x81, port, 0x11, 0x51, 0x00, speed};
    writeValue(setMotorCommand, 6);
}
```
- **📍 Running on**: Core 0 (BLE task context)
- **📝 Purpose**: LEGO Powered Up protocol implementation
- **🔧 Operations**:
  - Converts speed (50) to protocol format
  - Creates BLE characteristic write with motor command
  - Handles protocol-specific details and checksums
- **⏱️ Timing**: ~5-10ms for protocol formatting

### **Layer 8: NimBLE Stack & Hardware**
```cpp
// NimBLE Arduino Library + ESP32 Hardware
writeValue() → NimBLE characteristic write → BLE radio transmission
```
- **📍 Running on**: Core 0 (BLE task) + Hardware radio
- **📝 Purpose**: Actual Bluetooth communication to DUPLO hub
- **🔧 Operations**:
  - BLE GATT characteristic write
  - Bluetooth LE packet transmission to DUPLO hub
  - Hardware radio interface and antenna
- **⏱️ Timing**: ~10-20ms for BLE transmission

### **Layer 9: DUPLO Hub Hardware Response**
```
DUPLO Train Hub Hardware
├── Receives BLE packet with motor command
├── Parses LEGO Powered Up protocol
├── Applies PWM signal to motor (speed 50)
└── Motor starts rotating at specified speed
```
- **📍 Location**: DUPLO train hub hardware
- **📝 Purpose**: Physical motor control execution
- **⏱️ Timing**: ~5-10ms hardware response

### Complete Command Processing Timeline

```
┌────────────────────────────────────────────────────────────────────────┐
│                        COMMAND PROCESSING TIMELINE                     │
├────────────────────────────────────────────────────────────────────────┤
│                                                                        │
│ Time 0ms:   Application calls duploHub.setMotorSpeed(50)               │
│ Time 1ms:   Legacy wrapper calls setMotorSpeed_ThreadSafe(50)          │
│ Time 3ms:   Command packaged and queued to commandQueue                │
│ Time 4ms:   Command waits in FreeRTOS queue (Core 1 → Core 0)          │
│ Time ~25ms: BLE task processes command queue (max 50ms interval)       │
│ Time 27ms:  processCommandQueue() dequeues and executes command        │
│ Time 35ms:  Lpf2Hub formats LEGO protocol packet                       │
│ Time 45ms:  NimBLE transmits BLE packet to DUPLO hub                   │
│ Time 55ms:  DUPLO hub receives and processes command                   │
│ Time 60ms:  DUPLO train motor starts rotating at speed 50              │
│                                                                        │
│ TOTAL LATENCY: ~60ms from function call to physical motor response     │
└────────────────────────────────────────────────────────────────────────┘
```

### Command vs. Sensor Processing Comparison

| **Aspect** | **Command Processing** | **Sensor Processing** |
|---|---|---|
| **Direction** | Main Task → BLE Task | BLE Task → Main Task |
| **Trigger** | Application function call | Hardware sensor event |
| **Queue Type** | commandQueue (10 items) | responseQueue (100 items) |
| **Latency** | ~60ms (function → motor) | ~360ms (sensor → automation) |
| **Frequency** | On-demand (user commands) | Continuous (sensor events) |
| **Error Handling** | 100ms timeout, fallback | 100ms enqueue window, drop on timeout |
| **Criticality** | Medium (delayed commands OK) | High (stable automation feedback) |

### Command Processing Benefits

#### **Reliability**
- ✅ **100ms timeout**: Commands don't get lost, fallback to direct calls
- ✅ **Connection checking**: Commands only execute when hub is connected
- ✅ **Queue overflow handling**: System reports but continues functioning
- ✅ **Professional logging**: Every command execution is logged

#### **Performance**
- ✅ **Non-blocking application**: Main loop never waits for BLE operations
- ✅ **Batch processing**: Multiple commands processed in sequence
- ✅ **Predictable latency**: ~60ms maximum command-to-execution time
- ✅ **Efficient queuing**: Minimal memory and CPU overhead

#### **Architecture Benefits**
- ✅ **Thread safety**: No shared memory, all communication via queues
- ✅ **Clean separation**: Application logic isolated from BLE complexity
- ✅ **Extensible design**: Easy to add new command types
- ✅ **Professional debugging**: Comprehensive logging at each layer

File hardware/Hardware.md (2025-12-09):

# Duplo Train Controller Hardware

**Author:** Ralf Zühlsdorff  
**Copyright:** (c) 2025 Ralf Zühlsdorff  
**License:** MIT License

---

The hardware package covers both the custom ESP32-S3 controller PCB and the printable enclosure that transforms the electronics into a DUPLO-friendly handheld remote. Everything required to reproduce or iterate on the physical controller—KiCad sources, manufacturing files, OpenSCAD models, and helper assets—lives in this directory.

## Directory Layout

```
hardware/
├── Case/                       # OpenSCAD sources and library dependencies for the enclosure
├── DuploTrainController NG/    # KiCad PCB project and manufacturing outputs
└── README.md
```

The top-level `README.md` links back to the main project documentation and provides quick navigation hints for contributors.

## PCB Development

- The PCB is captured in KiCad 8 using `DuploTrainController NG.kicad_pro` as the entry point.
- A Tenstar ESP32-S3 SuperMini module forms the core, surrounded by button ladder, encoder, power management, and RGB LED circuitry sized for DUPLO ergonomics.
- `5 Buttons an ADC.xlsx` explains the resistor ladder math that multiplexes six push buttons into a single ADC input.
- Fabrication assets live under `Gerber/` and the zipped board archive `DuploTrainController NG.kicad_pcb.zip`. Review diffs carefully before committing regenerated output to avoid noise.
- Footprint cache data is retained in `fp-info-cache` so collaborators can rebuild without missing library references.

```
DuploTrainController NG/
├── DuploTrainController NG.kicad_pro   # KiCad project file (open this first)
├── DuploTrainController NG.kicad_sch   # Schematic for the controller PCB
├── DuploTrainController NG.kicad_pcb   # Routed PCB layout
├── DuploTrainController NG.kicad_prl   # Project-specific settings and plot config
├── DuploTrainController NG.kicad_pcb.zip
├── DuploTrainController NG-backups/    # Timestamped KiCad backups
│   └── DuploTrainController NG-*.zip
├── 5 Buttons an ADC.xlsx               # Button ladder calculations
├── Gerber/
│   ├── DuploTrainController NG-F_Cu.gbr
│   ├── DuploTrainController NG-Edge_Cuts.gbr
│   ├── DuploTrainController NG.drl
│   ├── DuploTrainController NG-job.gbrjob
│   └── GCode/
│       ├── F-CU.nc
│       ├── drill.nc
│       └── cutout.nc
└── fp-info-cache                       # Local footprint cache for reproducible builds
```

<p align="center">
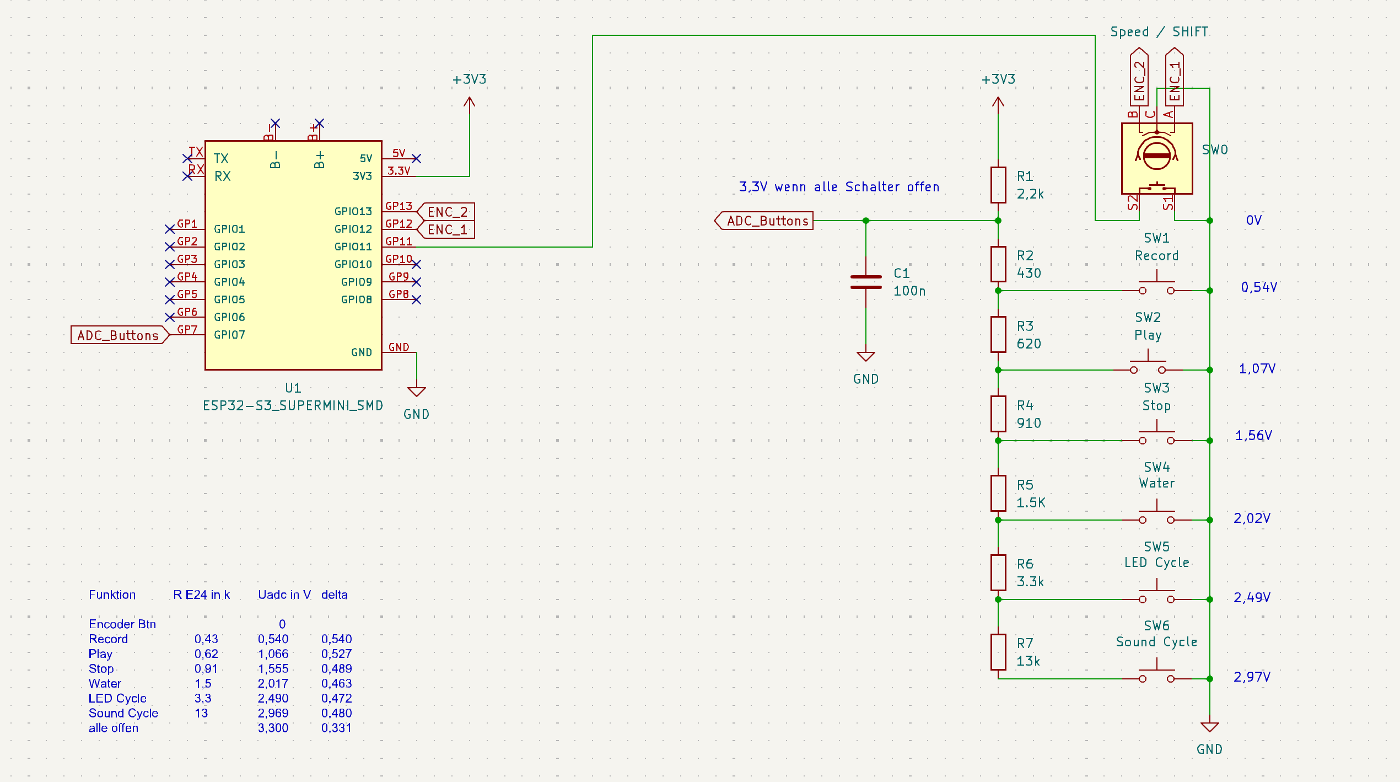
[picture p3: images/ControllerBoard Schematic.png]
Controller board schematic
	
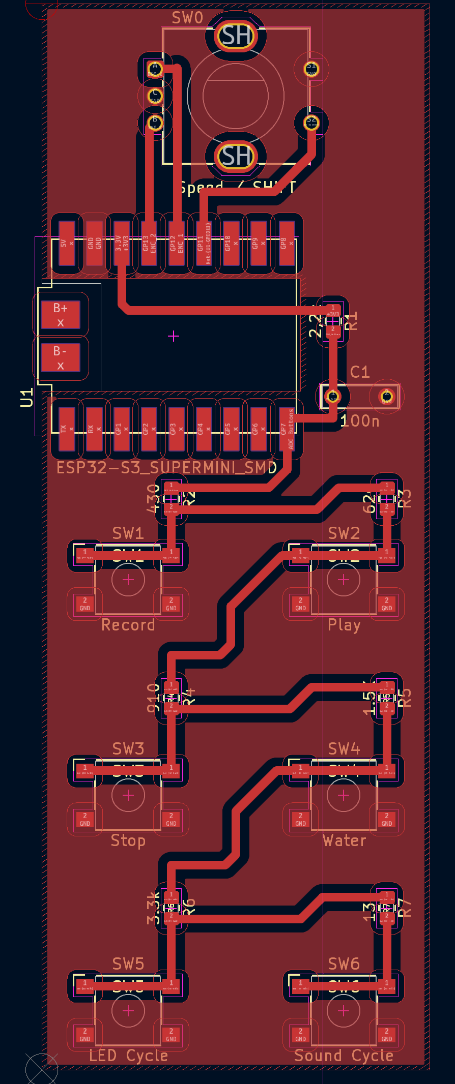
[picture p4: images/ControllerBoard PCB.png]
Controller board PCB layout
	
</p>

The 6 function buttons are handled via ADC input with ADCButton lib, so just one button at a time can be detected. The Excel sheet is used to calculate the resistors so that voltage difference between two steps is in the same range.

The encoder button is detected via a different GPIO pin for two reasons. First it provides a kind of second level for all function switches to implement future requirements. But main reason was that this button is used to wake the controller from deep sleep.

The Lithium 3.7V battery is connected to B+ and B- at the ESP32-S3. The schematic and PCB could be kept very simple as all functionality to handle charging is implemented by the ESP32-S3 Super Mini.

PCB has been produced by PCBWay.

## Case Development

- The enclosure is modelled in OpenSCAD inside `Case/Controller.scad`, assembling MachineBlocks primitives to match DUPLO dimensions.
- `Case/lib/` vendors the MachineBlocks modules to make the CAD fully reproducible without external dependencies.
- Parametric dimensions cover battery cavity, button spacing, and encoder fit, enabling quick iteration for future PCB tweaks.
- Export STL files from OpenSCAD before printing; small tolerances are already tuned for typical FDM printers.

```
Case/
├── Controller.scad            # Top-level OpenSCAD model for the enclosure
├── MachineBlocks/             # Upstream MachineBlocks sources (see vendor README)
└── lib/                       # Minimal subset of MachineBlocks modules used here
	├── base.scad
	├── block.scad
	├── connectors.scad
	├── duo.scad
	├── pcb.scad
	├── plug.scad
	├── shapes.scad
	├── socket.scad
	├── svg3d.scad
	└── text3d.scad
```

The case was designed based on a library and an example from MachineBlocks.
It covers the case with a bottom part and a lid with cutouts for 6 buttons, the encoder, and the USB connector.

There are 2 black buttons for recording (with red dot) and replay (with white triangle). The red button is used to initiate the emergency stop, the blue button is used for water refill, the white button to switch the headlight LED of the train, and the yellow to activate different sounds.

<p align="center">
	Controller Case
</p>

The design is provided as a SCAD file and export to 3MF and STL files have been added for 3D printing.

> **Note:** Both electrical and mechanical assets are version-controlled to keep the manufactured controller in sync with the firmware. When regenerating Gerbers or STLs, audit changes to ensure they reflect intentional design updates.

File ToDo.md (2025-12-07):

## Aktuelle ToDos

### 1. Record /Replay Funktion:
- [x] Die Replay Liste wird nicht nur genau einmal abgefahren sondern in einer Schleife -> Sollverhalten: Liste einmal abfahren und dann den Replay Modus beenden
- [x] Während Replay müssen alle Kommandos außer Beenden des Replaymodus und Stop ignoriert werden
- [x] Ebenso sollten die  über den Color Sensor identifizierten Aktionen im Replay Modus NICHT ausgeführt werden
- [x] Im Record Modus jedoch sollen die über den Color Sensor identifizierten Befehle mit aufgezeichnet werden
- [x] Das Timing der aufgezeichneten Befehle muss überprüft werden und sollte bis auf 500ms mit der Aufgezeichneten Sequenz beim Abspielen übereinstimmen

### 2. Sonstige Softwareänderungen
- [x] Der Voltage Sensor muss aktiviert werden um die Spannung der Duplobatterie zu überwachen. Klären bei welchem Soannungslevel eine Warnung ausgegeben werden soll (hat 4 AAA Batterien) -> Level wurde auf 6,0V gesetzt testweise
- [x] Die RGB LED auf dem Controller soll nur für Statusrückmeldungen verwendet werden:
  - [x] Initialisierung angeschlossen, Controller bereit -> von gelb leuchten, dann grün permanent
  - [x] Duplo Hub connected -> blau 3 x blinken dann aus
  - [x] Button Stop gedrückt -> rot dauer blinken, wird aufgehoben bei erneutem Drücken auf Stop
  - [x] Button Record gedrückt: -> blau dauer blinken, aufgehoben bei erneutem Drücken auf Record
  - [x] Button Play gedrückt: -> gelbes dauer blinken bis Sequenz abgeschlossen oder Record erneut gedrückt wurde
  - [x] Bei Disconnect des Duplo Hubs 3 x weiß blinken
  - [x] Duplo Batterie Level low: 10x hektisches Blinken in rot alle 30 Sekunden
  - [ ] Duplo Color Sensor gibt bei reflektierenden Oberflächen manchmal kurz hintereinander unterschiedliche Farbewerte aus
    - [ ] Sensor muss "entprellt" werden
      - [ ] Sensor Events innerhalb einer kurzen Zeitspanne (< 250ms) ignorieren
      - [ ] Aufruf des Callbacks nur, wenn Sensor Event länger als Zeitspanne (5000ms) stabil ist

- [ ] Controller Sleep Modus einbauen
  - [ ] wenn keine GUI Aktion für mehr als 5 Minuten soll der Controller in den Sleep Modus gehen
    - [ ] Im Sleep Modus wird nur die Stop Taste überwacht, z.B. über Interrupt
    - [ ] Wird die Stop TAste aktiviert wacht der Controller auf und geht in den Normalbetrieb
    - [ ] Im Sleep Modus blinkt die RGB LED schwach blau alle 2 Minuten. Mal sehen wie lange das der Akku mitmacht

### 3. Code Optimierungen

- [ ] Optimierung des Codes
  - [ ] Redundanzen ausbauen
  - [x] Klare Verteilung der Verantwortlichkeiten:
    - [x] DuploHub -> Verbindung zur Hardware, Senden von Befehlen und Weiterleiten von Sensordaten
    - [x] myLegoHub ergänzt und erweitert die Legoino Lib und wird nur von DuploHub verwendet
    - [x] TrainController ist für die Umsetzung der GUI Kommandos und die Verarbeitung von Sensorrückmeldungen verantwortlich
  - [x] Reduzieren der Delays so dass die Initialisierung und die Herstellung der Bereitschaft des Controller deutlich schneller geht. Auch die Latenz bei Kommandos mus reduziert werden. Klären welche minimalen Delays notwenndig sind damit die BLE Kommandos sicher ankommen.

### 4. Hardware Modifikationen
- [x] Modifikation der Platine:
- [ ] Controller Batterie Level Low: hecktisches Dauerblinken in rot - erfordert Modifikation der Platine und Überwachung der Spannung durch MCU -> aktuell nicht realisierbar
  - [x] Stop Button wird direkt über einen Digital Pin eingelesen
  - [x] Neben den Analog Buttons LED, Sound, Play und Replay noch einen Biutton für das Pairing und Wasseraufnehmen einbauen. -_> Pairing scheint nicht sinnvoll, da zu kompliziert
    - [ ] Bei Pairing wird die ID des aktuell verbundenen Zuges gespeichert und primär beim nächsten Connect verwendet. Wird kein Hub mit der gespeicherten ID nach 60 Sekunden gefunden wird jeder aktive Hub verbunden
    - [ ] Pairing kann aufgehoben werden durch erneutes drücken des Knopfes
    - [ ] Bei Drücken von Wasseraufnehmen wird die gleiche Aktionssequenz wie bei dem blauen Duploplättchen durchgeführt

### 5. Dokumentation
- [ ] Dokumentation des gesamten Systems überarbeiten:
  - [ ] HW Architektur
  - [ ] SW Architektur
  - [ ] Build und Inbetriebnahme
  - [ ] Benutzerhandbuch
- [ ] Design eines kindgerechten Gehäuses für den Controller

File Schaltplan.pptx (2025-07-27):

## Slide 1

Pin 25

3.3V

ESP32

Pin 25

Taster 1 gelb

Pin 26

Taster 2 weiß

220

Pin 15

Pin 24

Pin 27

Taster 3 blau

Taster 4 rot

Kann entfallen
Enn Rückmeldung
Akustisch erfolgt
(neue Version Sketch)

LED

Pin 12

Taster 5 Zugumschaltung

GND

GND

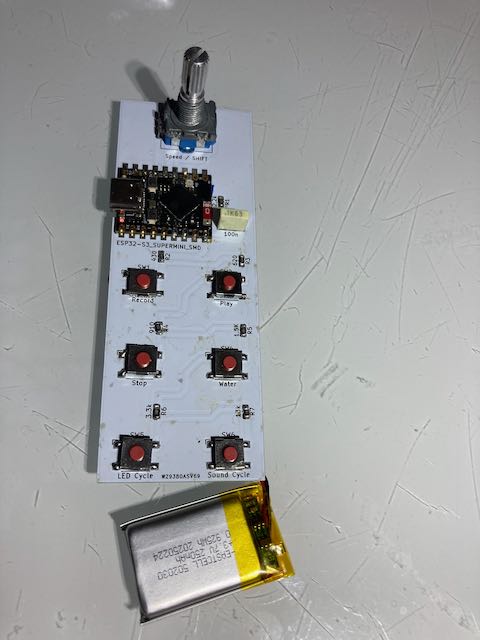
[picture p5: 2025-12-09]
images/PCB.jpeg

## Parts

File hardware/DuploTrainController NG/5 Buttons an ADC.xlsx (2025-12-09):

R0 | 2.2 | k |  | Rges in k | Rn in k | Uadc in V | Funktion | R E12 in k | Uadc in V | delta
closed |  |  |  |  |  | 0 | Encoder Btn |  | 0
x1 | 0.15 |  | R1 | 0.4 | 0.4 | 0.495 | Record | 0.39 | 0.497 | 0.497
x2 | 0.3 |  | R2 | 0.9 | 0.6 | 0.99 | Play | 0.56 | 0.995 | 0.498
x3 | 0.45 |  | R3 | 1.8 | 0.9 | 1.485 | Stop | 0.82 | 1.471 | 0.476
x4 | 0.6 |  | R4 | 3.3 | 1.5 | 1.98 | Water | 1.5 | 1.973 | 0.501
x5 | 0.75 |  | R5 | 6.6 | 3.3 | 2.475 | LED Cycle | 3.3 | 2.472 | 0.499
x6 | 0.9 |  | R5 | 19.8 | 13.2 | 2.97 | Sound Cycle | 12 | 2.950 | 0.478
open |  |  |  |  |  | 3.3 | alle offen |  | 3.300 | 0.350
 | Ucc | 3.3
 | Imax | 1mA

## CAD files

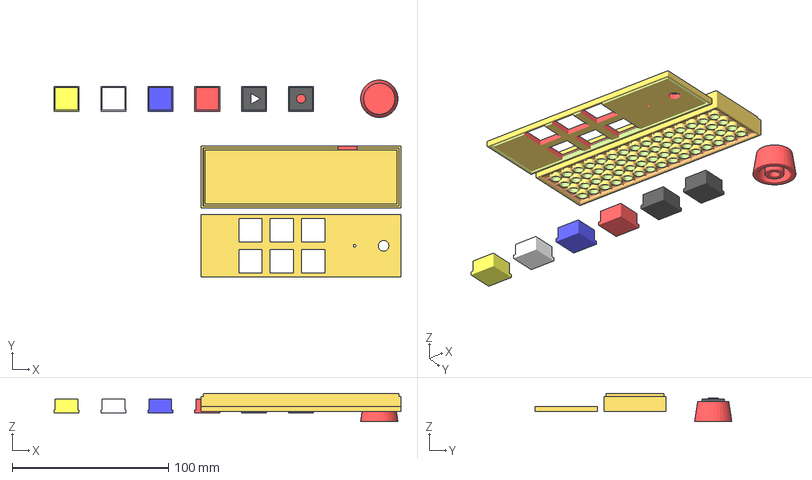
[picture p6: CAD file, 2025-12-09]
hardware/Case/Controller.3mf
221.9 x 125.8 x 18.1 mm

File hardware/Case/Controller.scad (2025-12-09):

/**
* MachineBlocks
* https://machineblocks.com/examples/boxes-enclosures
*
* Channel 12x3
* Copyright (c) 2022 - 2025 Jan Philipp Knoeller <pk@pksoftware.de>
*
* Published under license:
* Creative Commons Attribution-NonCommercial-ShareAlike 4.0 International 
* https://creativecommons.org/licenses/by-nc-sa/4.0/
*
*/
use <MachineBlocks/lib/block.scad>;

/* [View] */
// How to view the brick in the editor
viewMode = "print"; // [print, assembled, cover]

/* [Size] */

// Box size in X-direction specified as multiple of an 1x1 brick.
boxSizeX = 16; // [1:32] 
// Box size in Y-direction specified as multiple of an 1x1 brick.
boxSizeY = 5; // [1:32] 
// Total box height specified as number of layers. Each layer has the height of one plate.
boxLayers = 4; // [1:24]

/* [Appearance] */

// Type of cut-out on the underside.
baseCutoutType = "classic"; // [none, classic]
// Whether the base should have knobs
baseKnobs = false;
// Type of the base knobs
baseKnobType = "classic"; // [classic, technic]
// Whether base knobs should be centered.
baseKnobCentered = false;
// Whether the pit should contain knobs
basePitKnobs = false;
// Type of the base pit knobs
basePitKnobType = "classic"; // [classic, technic]
// Whether base pit knobs should be centered.
basePitKnobCentered = false;
// Pit wall thickness
basePitWallThickness = 0.333;
// Pit wall gaps
basePitWallGaps = [[0, 0, 0], [0, 0, 0]];
// Whether the base should have a tongue
baseTongue = true;

// Whether the box should have a lid
lid = true;
// Lid height specified as number of layers. Each layer has the height of one plate.
lidLayers = 1; // [1:24]
// Whether the lid should have knobs
lidKnobs = false;
// Type of the lid knobs
lidKnobType = "classic"; // [classic, technic]
// Whether lid knobs should be centered.
lidKnobCentered = false;
// Whether lid should have pillars
lidPillars = true;
// Whether lid should be permanent (non removable)
lidPermanent = true;

/* [Quality] */

// Quality of the preview in relation to the final rendering.
previewQuality = 0.5; // [0.1:0.1:1]
// Number of drawn fragments for roundings in the final rendering.
roundingResolution = 64; // [16:8:128]

/* [Calibration] */

//Adjustment of the height (mm)
baseHeightAdjustment = 0.0;
//Adjustment of each side (mm)
baseSideAdjustment = -0.1;
//Diameter of the knobs (mm)
knobSize = 5.0;
//Thickness of the walls (mm)
wallThickness = 1.5;
//Diameter of the Z-Tubes (mm)
tubeZSize = 6.4;


// Koordinatenpositionen vom Ursprungin Mitte des Deckels
l = 127.5;  // Laenge 16 Noppen aussen
b = 39.7;   // Breite 5 Noppen aussen
delta = 1;  // Abstand vom Innenwand

function toX0(x) = l/2 - wallThickness - delta - x;


// Alle x Positionen von oberer Kante

// Drehencoder 
enc_x = toX0(8.5); 
enc_y = 0;       
enc_r = 3.5;

// RGB LED
led_x = toX0(27.0);
led_y = 0;
led_r = 1;

// Ausbruch für Knöpfe
btn_dx = 15;
btn_dy = 15;


// Button (1,1)  Record
btn1_x = toX0(53.6);
btn1_y = 10;

// Button (1,2)  Play
btn2_x = toX0(53.6);
btn2_y = btn1_y - 20 ;

// Button (2,1)  Stop
btn3_x = toX0(53.6 + 20);
btn3_y = btn1_y ;

// Button (2,2)  LED
btn4_x = toX0(53.6 + 20);
btn4_y = btn1_y - 20;

// Button (3,1)  Water
btn5_x = toX0(53.6 + 2 * 20);
btn5_y = btn1_y;

// Button (3,2)  Sound
btn6_x = toX0(53.6 + 2 * 20);
btn6_y = btn1_y - 20;

// USB Typ C links
usb_x = toX0(31.5);  // mitte          
usb_z = 9.5;
usb_dz = 5;
usb_dx = 12;



module makeHole(x,y,r)
{
    echo("makeHole: Variable x = ", x);
    echo("Variable y = ", y);
    color([1,0,0])
        translate([x, y, 1])
            cylinder(10,r,r,true);
}


module makeRectHole(x,y,dx,dy)
{
    echo("makeRectHole: Variable x = ", x);
    echo("Variable y = ", y);
    color([1,0,0])
        translate([x, y, 0])
            cube([dx, dy, 10], center=true);
}


module makeLeftHole(x,z,dx,dz)
{
    echo("makeLeftHole: Variable x = ", x);
    echo("Variable z = ", z, "dz =", dz);
    color([1,0,0])
        translate([x, 18, z])
            cube([dx, 5, dz], center = true);
}


// Druckknöpfe
module button(farbe)
{
    color(farbe)
        {
            cube([16, 16, 2], center = true);
            translate([0,0,4])
                cube([14.5, 14.5, 8], center = true);
        }
}


module ButtonRecord(farbe){
    union(){
        button(farbe);
        translate([0,0,8])
            color([1,0,0])
                cylinder(1,3,3,true);
    }
}

module ButtonPlay(farbe){
    union(){
        button(farbe);
        translate([0,0,8])
            color([1,1,1])
                cylinder(1,4,4,true, $fn=3);
    }
}

// Knopf für Drehencoder
module Knob(farbe)
{
    height = 13;
    r1 = 12;
    r2 = 10;
    eps = 0.1;   // Klemmung
    w_wall = 2.5;
    r_hole = 3 - eps;
    
    color(farbe)
        {
            difference(){
                cylinder(height,r1,r2,true);
                translate([0,0,-2])
                    cylinder(height,r1-w_wall,r2-w_wall,true);
            }
            difference(){
                cylinder(height, r_hole + w_wall, r_hole + w_wall, true);
                translate([0,0,-w_wall])
                   cylinder(height,r_hole,r_hole, true);
            }
    }
}




module case() {
    color("yellow");
    difference() {
        block(
            grid=[boxSizeX, boxSizeY],
            baseLayers = boxLayers - (lid ? lidLayers : 0),
            baseCutoutType = baseCutoutType,

            knobs = baseKnobs,
            knobType = baseKnobType,
            knobCentered = baseKnobCentered,
            
            pit=true,
            //pitWallGaps = basePitWallGaps, //boxType != "box" ? (boxType == "channel_corner" ? [ [ 0, 0, 0 ], [ 2, 0, 0 ] ] : [ [ 0, 0, 0 ], [ 1, 0, 0 ] ]) : [],
            pitWallThickness = basePitWallThickness,
            pitKnobs = basePitKnobs,
            pitKnobType = basePitKnobType,
            pitKnobCentered = basePitKnobCentered,

            tongue = baseTongue,
            tongueHeight = lidPermanent ? 2.0 : 1.8,
            tongueClampThickness = lidPermanent ? 0.1 : 0,
            tongueOuterAdjustment = lidPermanent ? 0.0 : -0.1,
            tongueRoundingRadius = lidPermanent ? 0.0 : 0.4,
            
            baseHeightAdjustment = baseHeightAdjustment,
            baseSideAdjustment = baseSideAdjustment,
            knobSize = knobSize,
            wallThickness = wallThickness,
            tubeZSize = tubeZSize
        );
        makeLeftHole(usb_x,usb_z,usb_dx,usb_dz);
    }
}

module lid() {
    color("yellow");
    translate(viewMode != "print" ? [0, 0, ((boxLayers - lidLayers) + (viewMode == "cover" ? 2*lidLayers : 0)) * 3.2] : [boxSizeX > boxSizeY ? 0 : (boxSizeX + 0.5) * 8.0, boxSizeX > boxSizeY ? -(boxSizeY + 0.5) * 8.0 : 0, 0])
    {
            difference() {
            block(
                grid=[boxSizeX, boxSizeY],
                baseLayers = lidLayers,
                baseCutoutType = lidPermanent ? "groove" : "classic",

                knobs = lidKnobs,
                knobType = lidKnobType,
                knobCentered = lidKnobCentered,

                pillars = lidPillars,
                //pitWallGaps = basePitWallGaps, //boxType != "box" ? (boxType == "channel_corner" ? [ [ 0, 0, 0 ], [ 2, 0, 0 ] ] : [ [ 0, 0, 0 ], [ 1, 0, 0 ] ]) : [],

                baseHeightAdjustment = baseHeightAdjustment,
                baseSideAdjustment = baseSideAdjustment,
                knobSize = knobSize,
                wallThickness = wallThickness,
                tubeZSize = tubeZSize
            );
            makeHole(enc_x, enc_y, enc_r);
            makeHole(led_x, led_y, led_r);
            makeRectHole(btn1_x, btn1_y, btn_dx, btn_dy);
            makeRectHole(btn2_x, btn2_y, btn_dx, btn_dy);
            makeRectHole(btn3_x, btn3_y, btn_dx, btn_dy);
            makeRectHole(btn4_x, btn4_y, btn_dx, btn_dy);
            makeRectHole(btn5_x, btn5_y, btn_dx, btn_dy);
            makeRectHole(btn6_x, btn6_y, btn_dx, btn_dy);
        }
    }
}



translate([50,50,0]) 
    Knob("red");
translate([0,50,0])
    ButtonRecord("black");
translate([-30,50,0])
    ButtonPlay("black");

// Stop Button
translate([-60,50,0])
    button("red");

// Water Button
translate([-90,50,0])
    button("blue");

// LED Button
translate([-120,50,0])
    button("white");
    
// Sound Button
translate([-150,50,0])
    button("yellow");

// Unterteil
case();

// Deckel
if(lid){
    lid();
}

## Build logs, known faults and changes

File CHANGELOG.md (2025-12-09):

# Changelog

All notable changes to the DUPLO Train Controller project will be documented in this file.

The format is based on [Keep a Changelog](https://keepachangelog.com/en/1.0.0/), and this project adheres to [Semantic Versioning](https://semver.org/spec/v2.0.0.html).

## [2.1.0] - 2025-01-20

### Added

- **DuploHubExtended class** with bidirectional sensor data support
- **Sensor callback system** for color, distance, and button events
- **Second FreeRTOS queue** (sensorQueue) for BLE → Main task communication
- **Static callback wrappers** for seamless Lpf2Hub integration
- **Thread-safe sensor activation** via command queue system
- **TrainController_Extended.cpp** demonstrating color-based speed control
- **Real-time sensor processing** with ~50ms latency
- **Emergency distance detection** with automatic motor stopping
- **Button-based manual control** for train operation

### Enhanced
- **Architecture documentation** with bidirectional data flow diagrams
- **API reference** extended with sensor callback examples
- **Performance characteristics** for dual-queue communication system
- **Memory usage analysis** for sensor data processing
- **Complete sensor processing chain analysis** with 8-layer detailed flow
- **Processing timeline documentation** showing 75ms sensor-to-action latency
- **Layer-by-layer code examples** from hardware to application callbacks

### Technical Details
- Sensor data flows BLE Task (Core 0) → Main Task (Core 1) via sensorQueue
- Static callback integration bridges Lpf2Hub callbacks to queue system
- Non-blocking sensor data processing with configurable queue sizes
- Thread-safe sensor activation commands via existing command queue
- Complete backward compatibility with existing DuploHub API

## [2.0.0] - 2025-01-20

### Added
- **Multi-task architecture** with dedicated BLE task running on Core 0
- **Thread-safe command queue system** for inter-task communication
- **FreeRTOS integration** with proper synchronization primitives
- **Automatic connection recovery** with background reconnection logic
- **System health monitoring** with task status checking
- **Professional logging system** with component-specific prefixes
- **TrainController.cpp** as main application (renamed from TrainHub.cpp)
- **DuploHub class** as hardware abstraction layer
- **Comprehensive documentation** including README, Quick Reference, and Architecture guide

### Changed
- **Complete refactoring** from single-threaded to multi-threaded architecture
- **Connection management** moved to background task for non-blocking operation
- **Command execution** now uses queue-based system instead of direct calls
- **Error handling** improved with graceful degradation and recovery
- **Performance optimization** with dual-core ESP32 utilization

### Improved
- **Responsiveness**: Main loop never blocks on BLE operations
- **Reliability**: Automatic task recovery and connection management
- **Maintainability**: Clean separation of concerns between layers
- **Debuggability**: Detailed logging and status monitoring
- **Code quality**: Thread-safe design patterns throughout

## [1.0.0] - 2025-01-19

### Added
- **Initial project structure** with basic DUPLO train control
- **DuploHub class** with basic connection management
- **Connection callbacks** for hub connect/disconnect events
- **Motor control** with speed setting and stop functionality
- **LED control** with color changes
- **Demo sequence** with automatic train operation
- **Serial monitoring** with basic status output

### Technical Details
- Single-threaded architecture using Arduino loop
- Direct Lpf2Hub integration for BLE communication
- Basic connection state tracking
- Simple demo state machine

### Dependencies
- Legoino library for LEGO Powered Up protocol
- NimBLE-Arduino for Bluetooth LE communication
- ESP32 Arduino framework

## [0.1.0] - 2025-01-18 (Initial Development)

### Added
- **Project initialization** with PlatformIO setup
- **Basic Lpf2Hub integration** from Legoino library
- **ESP32 platform configuration**
- **Initial connection attempts** to DUPLO train hub
- **Proof of concept** motor control commands

### Development Notes
- Started as simple example modification
- Explored Legoino library capabilities
- Established basic BLE connectivity
- Verified ESP32 compatibility with LEGO hubs

---

## Upgrade Guide

### From 1.0.0 to 2.0.0

The 2.0.0 release introduces breaking changes due to the multi-task architecture:

#### Required Code Changes

1. **Update setup() function**:
   ```cpp
   // Old (1.0.0)
   void setup() {
       duploHub.init();
   }
   
   // New (2.0.0)
   void setup() {
       duploHub.startBLETask();  // Start background BLE task
   }
   ```

2. **Update main loop**:
   ```cpp
   // Old (1.0.0)
   void loop() {
       if (!duploHub.isConnected()) {
           duploHub.init();
       }
       // ... direct control code
   }
   
   // New (2.0.0)
   void loop() {
       duploHub.update();  // Only handle callbacks
       // ... application logic (no direct BLE calls)
   }
   ```

3. **Thread-safe commands** (automatically handled by backward compatibility):
   ```cpp
   // These calls are now automatically thread-safe
   duploHub.setMotorSpeed(50);
   duploHub.setLedColor(RED);
   ```

#### Benefits After Upgrade
- Non-blocking BLE operations
- Automatic connection recovery
- Better system responsiveness
- Professional status monitoring
- Improved error handling

## Compatibility Matrix

| Version | ESP32 Core | Arduino Framework | PlatformIO | NimBLE | Legoino |
|---|---|---|---|---|---|
| 2.0.0 | ≥2.0.0 | ≥2.0.0 | ≥6.0.0 | ≥1.4.0  | ≥1.8.0  |
| 1.0.0 | ≥1.0.6 | ≥1.0.6 | ≥5.0.0 | ≥1.3.0  | ≥1.7.0  |
| 0.1.0 | ≥1.0.4 | ≥1.0.4 | ≥4.0.0 | ≥1.2.0  | ≥1.6.0  |

## Known Issues

### Version 2.0.0
- Initial BLE scan may take up to 10 seconds on first boot
- Memory usage increased due to FreeRTOS objects (~2KB additional)
- Debug output may be verbose during development

### Version 1.0.0
- BLE operations could block main loop for several seconds
- No automatic recovery from connection failures
- Limited error handling and status reporting

## Contributors

- **System Architecture**: Multi-task design and FreeRTOS integration
- **Hardware Abstraction**: DuploHub class design and thread-safe API
- **Documentation**: Comprehensive guides and API documentation
- **Testing**: Hardware validation with DUPLO train systems

## Acknowledgments

- **Cornelius Munz** - Original Legoino library
- **ESP32 Community** - Arduino framework and examples
- **LEGO Group** - DUPLO and Powered Up specifications

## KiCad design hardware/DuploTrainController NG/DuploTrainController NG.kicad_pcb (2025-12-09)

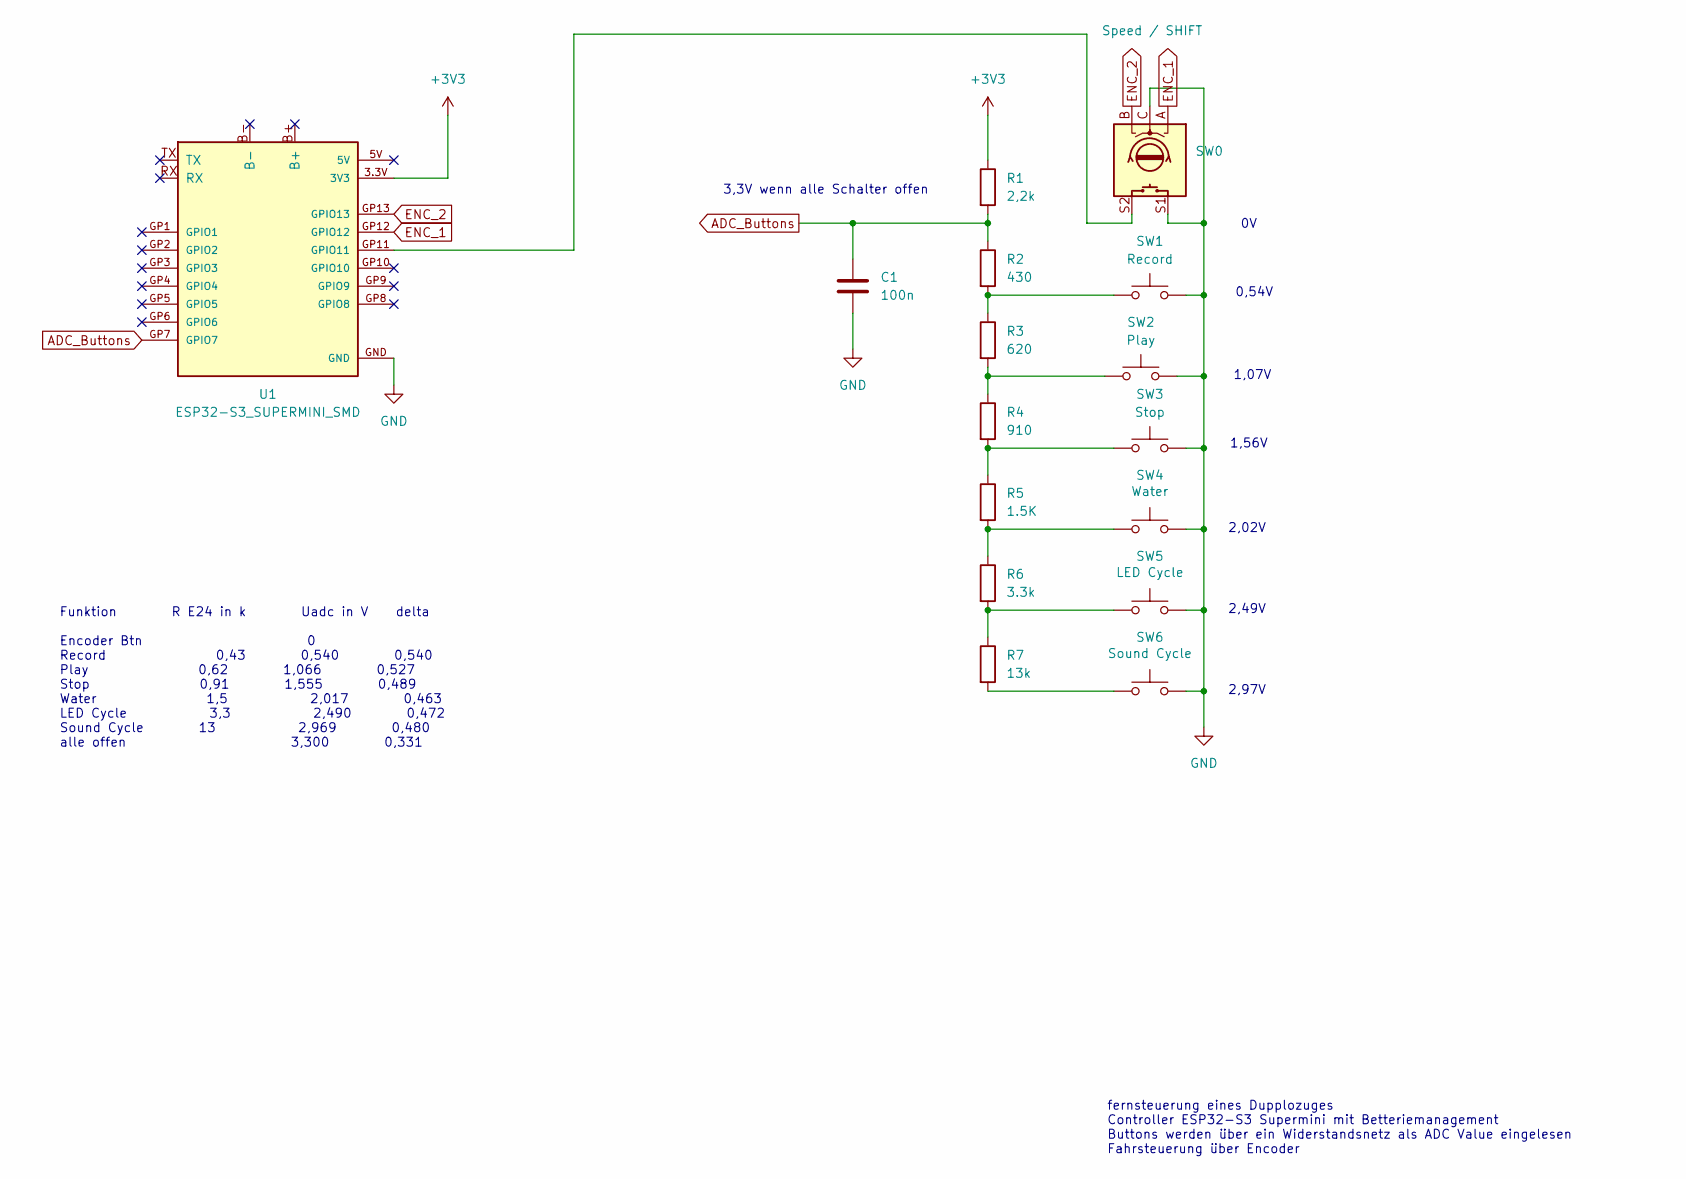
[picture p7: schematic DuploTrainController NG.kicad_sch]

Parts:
C1: 100n; C_Rect_L7.0mm_W2.0mm_P5.00mm
R1: 2,2k; R_0805_2012Metric_Pad1.20x1.40mm_HandSolder
R2: 430; R_0805_2012Metric_Pad1.20x1.40mm_HandSolder
R3: 620; R_0805_2012Metric_Pad1.20x1.40mm_HandSolder
R4: 910; R_0805_2012Metric_Pad1.20x1.40mm_HandSolder
R5: 1.5K; R_0805_2012Metric_Pad1.20x1.40mm_HandSolder
R6: 3.3k; R_0805_2012Metric_Pad1.20x1.40mm_HandSolder
R7: 13k; R_0805_2012Metric_Pad1.20x1.40mm_HandSolder
SW0: Speed / SHIFT; RotaryEncoder_Bourns_Vertical_PEC12R-3x17F-Sxxxx
SW1: Record; SW_SPST_Omron_B3FS-101xP
SW2: Play; SW_SPST_Omron_B3FS-101xP
SW3: Stop; SW_SPST_Omron_B3FS-101xP
SW4: Water; SW_SPST_Omron_B3FS-101xP
SW5: LED Cycle; SW_SPST_Omron_B3FS-101xP
SW6: Sound Cycle; SW_SPST_Omron_B3FS-101xP
U1: ESP32-S3_SUPERMINI_SMD; MODULE_ESP32-S3_SUPERMINI_SMD

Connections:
+3V3: R1.1, U1.3.3V (3V3)
ADC_Buttons: C1.1, R1.2, R2.1, U1.GP7 (GPIO7)
ENC_1: SW0.A, U1.GP12 (GPIO12)
ENC_2: SW0.B, U1.GP13 (GPIO13)
GND: C1.2, SW0.C, SW0.S1, SW1.2, SW2.2, SW3.2, SW4.2, SW5.2, SW6.2, U1.GND
unnamed: R2.2, R3.1, SW1.1
unnamed: R3.2, R4.1, SW2.1
unnamed: R4.2, R5.1, SW3.1
unnamed: R5.2, R6.1, SW4.1
unnamed: R6.2, R7.1, SW5.1
unnamed: R7.2, SW6.1
unnamed: SW0.S2, U1.GP11 (GPIO11)

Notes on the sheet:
2,02V
0,54V
2,49V
1,07V
fernsteuerung eines Dupplozuges Controller ESP32-S3 Supermini mit Betteriemanagement Buttons werden über ein Widerstandsnetz als ADC Value eingelesen Fahrsteuerung über Encoder
3,3V wenn alle Schalter offen
2,97V
Funktion R E24 in k Uadc in V delta Encoder Btn 0 Record 0,43 0,540 0,540 Play 0,62 1,066 0,527 Stop 0,91 1,555 0,489 Water 1,5 2,017 0,463 LED Cycle 3,3 2,490 0,472 Sound Cycle 13 2,969 0,480 alle offen 3,300 0,331
1,56V

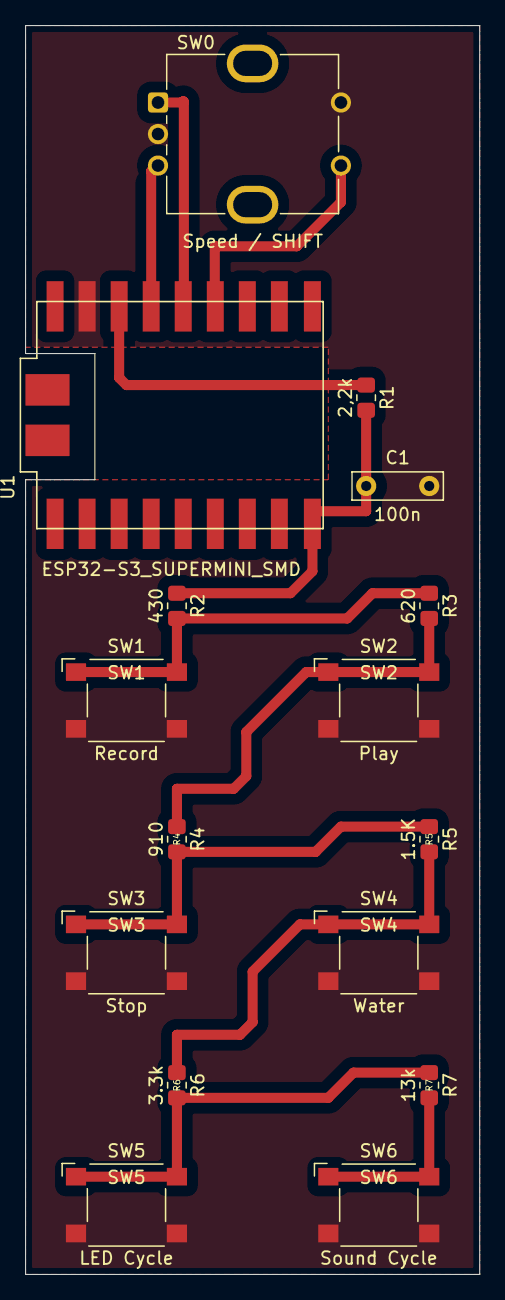
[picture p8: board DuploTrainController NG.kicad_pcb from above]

Board: 2 copper layers, 36.0 x 99.0 mm, 16 parts (0 on the bottom side), 12 nets.

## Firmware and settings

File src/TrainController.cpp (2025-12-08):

/**
 * @file TrainController.cpp
 * @brief Main application for LEGO DUPLO Train control using DuploHub on ESP32.
 *
 * This file implements the main application logic for controlling a LEGO DUPLO train
 * using the DuploHub class and ESP32 dual-core architecture. It demonstrates a modular,
 * event-driven approach to BLE-based train control, with robust handling of motor, LED,
 * and sound commands, as well as real-time sensor feedback and user input.
 *
 * Architecture:
 * - TrainController: Main application logic (this file)
 * - DuploHub: Hardware abstraction layer with multi-task BLE management
 * - Lpf2Hub: Low-level LEGO Powered Up protocol implementation
 *
 * Features:
 * - Dual-core, multi-task architecture (BLE on Core 0, main loop on Core 1)
 * - Thread-safe command queuing for motor, LED, and sound control
 * - Real-time status monitoring, logging, and error handling
 * - Automatic BLE connection management and recovery
 * - Modular callback system for sensor and event handling
 * - Record and replay of command sequences for automated demos
 * - Emergency stop and user input via debounced buttons and rotary encoder
 *
 * Demo Sequence:
 * - LED color changes (GREEN, RED, etc.)
 * - Motor control (forward, backward, stop)
 * - Sound playback (HORN, BELL, WATER_REFILL, etc.)
 *
 * @author Ralf Zühlsdorff
 * @date 2025
 *
 * @copyright
 * MIT License
 *
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
 * THE SOFTWARE IS PROVIDED "AS IS", WITHOUT WARRANTY OF ANY KIND, EXPRESS OR
 * IMPLIED, INCLUDING BUT NOT LIMITED TO THE WARRANTIES OF MERCHANTABILITY,
 * FITNESS FOR A PARTICULAR PURPOSE AND NONINFRINGEMENT. IN NO EVENT SHALL THE
 * AUTHORS OR COPYRIGHT HOLDERS BE LIABLE FOR ANY CLAIM, DAMAGES OR OTHER
 * LIABILITY, WHETHER IN AN ACTION OF CONTRACT, TORT OR OTHERWISE, ARISING FROM,
 * OUT OF OR IN CONNECTION WITH THE SOFTWARE OR THE USE OR OTHER DEALINGS IN THE
 * SOFTWARE.
 */

/*
NEXT GENERATION DUPLO TRAIN CONTROLLER

ONLY ON ESP§"S§

*/

#include "DuploHub.h"
#include "SystemMemory.h"

#undef DEBUG // Enable debug logging
#include "debug.h"
#include "ADCButton.h"
#include "StatusLED.h"

#include "driver/rtc_io.h"
#include "esp_sleep.h"

#include <ESP32RotaryEncoder.h>

#define DELAY_TIME 100 // delay in ms

// Pin declaration
// All buttons are wired through a resistor ladder to ADC pin 7 and decoded by voltage level.
// Current calibration (12-bit ADC values) for the GUI button helpers:
// - Record: ~450-750  → starts/stops recording the command stream
// - Play:   ~1000-1400 → toggles replay mode and command playback
// - Stop:   ~1650-2000 → toggles the emergency stop or halts replay immediately
// - Water:  ~2200-2550 → plays the water refill sound effect
// - Light:  ~2800-3150 → cycles the hub LED through the DUPLO color palette
// - Sound:  ~3500-3900 → advances to the next horn/brake sound sample
// Re-run calibrateButtons() if your hardware uses different resistor values.

#define ADC_PIN 7 // Button ADC pin (GPIO 7)

// Speed is defined via rotary encoder
#define ENCODER_A 12 // Encoder A pin
#define ENCODER_B 13 // Encoder B pin
#define ENCODER_BTN 11 // Encoder button pin

// Create rotary encoder instance
RotaryEncoder rotaryEncoder = RotaryEncoder(ENCODER_A, ENCODER_B); //, ENCODER_BTN);

// Onboard RGB LED
#define DATA_PIN 48

// define low voltage threshold for voltage sensor
#define LOW_VOLTAGE_THRESHOLD 5.0f // Voltage threshold for low battery warning

StatusLED statusLed(DATA_PIN); // Pin 48 for ESP32-S3-DevKitC-1

// TrainController instance with DuploHub for BLE communication
DuploHub duploHub;

// record user action time of last user action
unsigned long lastUserActionTime = 0;
#define maxIdleTime 300000 // 300 seconds until going to sleep

// Determine which button is pressed based on ADC value
static bool soundPressed = false;
static bool lightPressed = false;
static bool recordPressed = false;
static bool playPressed = false;
static bool stopPressed = false;

static int detectedSpeed = 0;
static float detectedVoltage = 0.0f;
static int detectedColor = 0;
static int potiSpeed = 0;
static bool emergencyStop = false;

static bool recording = false;
static bool playback = false;
static bool replay = false; // true when a sequence is being replayed

ADCButtons guiButtons = ADCButtons(ADC_PIN);

// Button numbers for GUI buttons
enum GUIButtons
{
    BUTTON_RECORD,
    BUTTON_PLAY,
    BUTTON_STOP,
    BUTTON_WATER,
    BUTTON_LIGHT,
    BUTTON_SOUND
};

// mapping between Duplo Colors and CRGB Colors
// index corresponds to DuploColor enum values
// 0 = BLACK, 1 = PINK, 2 = PURPLE, etc.
CRGB::HTMLColorCode rgbColors[] = {
    CRGB::Black,
    CRGB::Pink,
    CRGB::Purple,
    CRGB::Blue,
    CRGB::LightBlue,
    CRGB::Cyan,
    CRGB::Green,
    CRGB::Yellow,
    CRGB::Orange,
    CRGB::Red,
    CRGB::White};

/**
 * @brief Handles button presses for sound, light, water, and emergency stop.
 *
 * Cycles through sounds and LED colors, triggers water sound, and toggles emergency stop.
 */
void handleButtons(int btn_no, bool pressed)
{

    DEBUG_LOG("TrainController: Button %d is %s", btn_no, pressed ? "pressed" : "released");

    static int color = 0; // Color index for LED cycling
    static int duploSounds[] = {
        DuploEnums::DuploSound::HORN,
        DuploEnums::DuploSound::BRAKE,
        DuploEnums::DuploSound::WATER_REFILL,
        DuploEnums::DuploSound::STATION_DEPARTURE,
        DuploEnums::DuploSound::STEAM};
    static int sound = 0; // Sound index for sound playbook

    if (pressed == false || !duploHub.isConnected())
        return;

    lastUserActionTime = millis();

    // If replay is active, only STOP and PLAY (replay) buttons are allowed
    if (replay && btn_no != BUTTON_STOP && btn_no != BUTTON_PLAY) {
        DEBUG_LOG("TrainController: Ignoring button %d during replay", btn_no);
        return;
    }

    switch (btn_no)
    {
    case BUTTON_SOUND:
        sound++;
        if (sound == 2) sound = 3; // skip WATER_REFILL sound
        if (sound == 5) sound = 0;
        duploHub.playSound((DuploEnums::DuploSound)duploSounds[sound]);
        DEBUG_LOG("TrainController: Sound button pressed, playing sound %d", sound);
        delay(DELAY_TIME);
        break;
    case BUTTON_LIGHT:
        color = (color + 1) % 11; // Cycle through DuploColor enum values
        duploHub.setLedColor((DuploEnums::DuploColor)color);
        DEBUG_LOG("TrainController: Light button pressed, color %d", color);
        delay(DELAY_TIME);
        break;
    case BUTTON_WATER:
        color = (color + 1) % 11; // Cycle through DuploColor enum values
        duploHub.playSound((DuploEnums::DuploSound)duploSounds[2]); // Play WATER_REFILL sound
        DEBUG_LOG("TrainController: Light button pressed, color %d", color);
        delay(DELAY_TIME);
        break;
    case BUTTON_RECORD:
        DEBUG_LOG("TrainController: start or stop recording");
        recording = !recording; // Toggle recording state
        // stop playback if recording is active
        if (recording)
        {
            DEBUG_LOG("TrainController: Recording started");
            statusLed.setColor(CRGB::Red); // Blink red when recording
            statusLed.setBlinking(true, 500, 1000);
            duploHub.recordCommands(true); // Start recording commands
            delay(DELAY_TIME);             // Allow time for sound to play
        }
        else
        {
            DEBUG_LOG("TrainController: Recording stopped");
            duploHub.recordCommands(false); // Stop recording commands
            statusLed.setOff();             // LED off when recording stops
            delay(DELAY_TIME); // Allow time for sound to play
        }
        break;
    case BUTTON_PLAY:
        DEBUG_LOG("TrainController: start or stop playback");
        // disable playback when recording is active
        if (recording)
        {
            DEBUG_LOG("TrainController: Playback disabled while recording is active");
            return; // Ignore playback if recording is active
        }
        playback = !playback; // Toggle playback state  
        if (playback)
        {
            duploHub.replayCommands();
            statusLed.setColor(CRGB::Yellow);           // Blink yellow during replay
            statusLed.setBlinking(true, 500, 1000);
            replay = true; // Set replay mode
        }
        else
        {
            duploHub.stopReplay();
            statusLed.setOff();
            replay = false; // End replay mode
        }
        DEBUG_LOG("TrainController: Playback %s", playback ? "started" : "stopped");
        delay(DELAY_TIME);
        break;
    case BUTTON_STOP:
        emergencyStop = !emergencyStop; // Toggle emergency stop state
        // If replay is active, stop replay and playback immediately
        if (replay) {
            duploHub.stopReplay();
            statusLed.setOff();
            playback = false;
            replay = false;
            DEBUG_LOG("TrainController: STOP pressed during replay, replay stopped");
            return;
        }
        if (emergencyStop)
        {
            statusLed.setColor(CRGB::Red); // Solid red when stop is active
            statusLed.setBlinking(false);
            duploHub.playSound((DuploEnums::DuploSound::BRAKE)); // Play brake sound
            delay(DELAY_TIME);                                   // Allow time for sound to play
            duploHub.setLedColor(DuploEnums::DuploColor::RED);
            delay(DELAY_TIME);
            duploHub.stopMotor();
            delay(DELAY_TIME); // Stop the motor immediately
            rotaryEncoder.setEncoderValue(0);
        }
        else
        {
            duploHub.playSound((DuploEnums::DuploSound::STATION_DEPARTURE)); // Play departure sound
            delay(DELAY_TIME);                                               // Allow time for sound to play
            duploHub.setLedColor(DuploEnums::DuploColor::GREEN);             // Set LED to green
            statusLed.setOff(); // LED off when stop is released
            delay(DELAY_TIME); // Allow time for sound to play
        }
        DEBUG_LOG("TrainController: Emergency stop %s", emergencyStop ? "activated" : "deactivated");
        delay(DELAY_TIME);
        break;
    default:
        DEBUG_LOG("TrainController: Unknown button %d", btn_no);
        return; // Ignore unknown buttons
    }
}

// Sets the speed of the currently selected train
#define MIN_SPEED 10
#define MAX_SPEED 100
#define SPEED_INC 5
#define POTI_DELAY 250

static int lastSpeed = 0; // holds current mapping of poti setting to speed

/**
 * @brief Handles potentiometer input and sets train speed accordingly.
 *
 * Stops the train if emergency stop is active or if the potentiometer is in the zero zone.
 */
static void handleEncoder(long speed)
{
    static long lastCall = millis();

    DEBUG_LOG("TrainController: Set motor speed to %d", speed);

    if (emergencyStop)
    {
        duploHub.setMotorSpeed(0);        // Stop the motor immediately
        rotaryEncoder.setEncoderValue(0); // Reset encoder value
        delay(DELAY_TIME);
        DEBUG_LOG("TrainController: Emergency stop activated, motor speed set to 0");
        return; // Exit if emergency stop is active
    }

    if (millis() - lastCall > POTI_DELAY)
    {
        lastCall = millis(); // Update last call time

        // if emergencyStop triggered or poti in zero zone
        if (speed > -MIN_SPEED && speed < MIN_SPEED)
        {
            duploHub.setMotorSpeed(0);
            lastSpeed = 0; // Reset lastSpeed to avoid repeated calls
        }
        else
        {
            // train speed changed
            lastUserActionTime = millis();
            duploHub.setMotorSpeed(speed);
            lastSpeed = speed;
        }
        delay(DELAY_TIME);
        DEBUG_LOG("TrainController: Set motor speed to %d", lastSpeed);
    }
}

/**
 * @brief Handle presses of the encoder push button.
 *
 * The callback ignores presses while the hub is disconnected, preventing spurious actions during
 * reconnection. The timestamp provided by the driver is not needed in this implementation.
 *
 * @param pressTime Millisecond timestamp supplied by the encoder library.
 */
static void handleEncoderBtn(unsigned long pressTime)
{
    (void)pressTime;

    if(!duploHub.isConnected())
        return;

    DEBUG_LOG("TrainController: Encoder button pressed");
}


// Function to process the responseQueue and print detected color
/**
 * @brief Callback for detected color events from the color sensor.
 * @param color The detected color (DuploEnums::DuploColor).
 */
static void detectedColorCb(DuploEnums::DuploColor color)
{
    if (replay || recording) {
        DEBUG_LOG("TrainController: Color sensor callback ignored during recording and replay");
        return;
    }

    DEBUG_LOG("TrainController:  Detected Color: %d", color);

    detectedColor = color; // Store the detected color
    switch (color)
    {
    case DuploEnums::DuploColor::BLACK:
        DEBUG_LOG("TrainController:  Detected Color: %d", DuploEnums::DuploColor::BLACK);   
        duploHub.setLedColor(DuploEnums::DuploColor::BLACK);
        statusLed.setColor(CRGB::Black);
        delay(DELAY_TIME);
        break;
    case DuploEnums::DuploColor::RED:
        DEBUG_LOG("TrainController:  Detected Color: %d", DuploEnums::DuploColor::RED);
        emergencyStop = !emergencyStop; // Toggle emergency stop state
        statusLed.setColor(CRGB::Red);
        statusLed.setBlinking(true, 250, 250, 3); // Set LED color to white
        delay(DELAY_TIME);
        duploHub.playSound((DuploEnums::DuploSound::BRAKE)); // Play brake sound
        delay(DELAY_TIME);                                   // Allow time for sound to play
        duploHub.setLedColor(DuploEnums::DuploColor::RED);
        delay(DELAY_TIME);
        break;
    case DuploEnums::DuploColor::YELLOW:
        DEBUG_LOG("TrainController:  Detected Color: %d", DuploEnums::DuploColor::YELLOW);
        duploHub.setLedColor(DuploEnums::DuploColor::YELLOW);
        statusLed.setColor(CRGB::Yellow);
        statusLed.setBlinking(true, 250, 250, 3); // Set LED color to white
        delay(DELAY_TIME);
        duploHub.playSound((DuploEnums::DuploSound::HORN)); // Play horn sound
        delay(DELAY_TIME);                                  // Allow time for sound to play
        break;
    case DuploEnums::DuploColor::BLUE:
        DEBUG_LOG("TrainController:  Detected Color: %d", DuploEnums::DuploColor::BLUE);
        duploHub.setLedColor(DuploEnums::DuploColor::BLUE);
        statusLed.setColor(CRGB::Blue);
        statusLed.setBlinking(true, 250, 250, 3); // Set LED color to white
        delay(DELAY_TIME);
        duploHub.stopMotor();
        delay(DELAY_TIME);                                          // Stop the motor
        duploHub.playSound((DuploEnums::DuploSound::WATER_REFILL)); // Play water refill sound
        delay(DELAY_TIME);                                          // Allow time for sound to play
        duploHub.setMotorSpeed(lastSpeed);                          // Restore the last speed
        delay(DELAY_TIME);
        break;
    case DuploEnums::DuploColor::WHITE:
        DEBUG_LOG("TrainController:  Detected Color: %d", DuploEnums::DuploColor::WHITE);
        for (int i = 0; i < 3; i++)
        {
            duploHub.setLedColor(DuploEnums::DuploColor::WHITE);
            statusLed.setColor(CRGB::White);
            statusLed.setBlinking(true, 250, 250, 3); // Set LED color to white
        }
        break;
    default:
        DEBUG_LOG("TrainController:  Default Color action: %d", color);
        duploHub.setLedColor(color);
    }
}

// Function to process the responseQueue and print detected voltage
/**
 * @brief Callback for detected voltage events from the voltage sensor.
 * @param voltage The detected voltage value.
 */
// Only execute callback if time since last execution > CALC_VOLTAGE_DELAY
#ifndef CALC_VOLTAGE_DELAY
#define CALC_VOLTAGE_DELAY 5000 // ms, default if not defined elsewhere
#endif
static void detectedVoltageCb(float voltage)
{
    static unsigned long lastExec = 0;
    unsigned long now = millis();
    if (now - lastExec < CALC_VOLTAGE_DELAY) {
        return;
    }
    lastExec = now;
    DEBUG_LOG("TrainController:  Detected Voltage: %.2f V", voltage);
    detectedVoltage = voltage;
}

// Function to process the responseQueue and print detected color
/**
 * @brief Callback for detected speed events from the speed sensor.
 * @param speed The detected speed value.
 */
static void detectedSpeedCb(int speed)
{
    DEBUG_LOG("TrainController:  Detected Speed: %d", speed);
    detectedSpeed = speed;
}

// Callback function when hub connects
/**
 * @brief Callback function called when the hub is connected.
 *
 * Activates all relevant ports and registers sensor callbacks.
 */
String duploHubAddress = "";

static void onHubConnected()
{
    DEBUG_LOG("TrainController: Hub instance connected, starting initialization...");
    statusLed.setColor(CRGB::Blue);           // Set color to blue
    statusLed.setBlinking(true, 200, 300, 3); // Blink blue 3x
    delay(1800);                              // Wait for 3 blinks (3 * (200+300) ms)
    statusLed.setOff();                       // Turn LED off after blinking

    // reset user activity timer to start value
    lastUserActionTime = millis();

#ifdef DEBUG
    duploHub.listDevicePorts(); // List connected devices on the hub
    delay(1000);
#endif

    duploHub.activateRgbLight();
    delay(200);
    duploHub.activateBaseSpeaker();
    delay(200);
    duploHub.activateColorSensor();
    delay(200);
    duploHub.activateSpeedSensor();
    delay(200);
    duploHub.activateVoltageSensor();
    delay(200);
    DEBUG_LOG("DuploHub: All ports activated");

    duploHub.setDetectedColorCallback(detectedColorCb);
    delay(200);
    duploHub.setDetectedSpeedCallback(detectedSpeedCb);
    delay(200);
    duploHub.setDetectedVoltageCallback(detectedVoltageCb);
    delay(200);
    DEBUG_LOG("DuploHub: All callbacks registered");

    duploHub.setHubName("DuploTrain_1");
    delay(200);
    
    duploHubAddress = String(duploHub.getHubAddress().c_str());

    DEBUG_LOG("TrainController: Connected to hub: %s", duploHub.getHubName().c_str());
    DEBUG_LOG("TrainController: Hub address: %s", duploHubAddress.c_str());
}

// Callback function when hub disconnects
/**
 * @brief Callback function called when the hub is disconnected.
 */
static void onHubDisconnected()
{
    DEBUG_LOG("TrainController: Hub disconnected - stopping all operations");
    statusLed.setColor(CRGB::White);          // Set color to white
    statusLed.setBlinking(true, 200, 300, 3); // Blink white 3x
    delay(1800);                              // Wait for 3 blinks (3 * (200+300) ms)
    statusLed.setOff();                       // Turn LED off after blinking
}
/**
 * @brief Execute the next recorded command when its playback timestamp arrives.
 *
 * Pulls commands from the hub's replay buffer in chronological order, skipping execution if the
 * emergency stop is active. When the sequence completes, the LED and replay flags are reset.
 */
void replayNextCommand()
{
    const HubCommand *cmd = duploHub.getNextReplayCommand();
    if (cmd == nullptr)
    {
        // If replay is no longer active, stop playback and update LED
        if (!duploHub.isReplayActive()) {
            playback = false;
            replay = false;
            statusLed.setBlinking(false); // Stop blinking first
            statusLed.setOff();           // LED off when replay ends
            DEBUG_LOG("TrainController: No more commands to replay, stopping replay");
        } else {
            DEBUG_LOG("TrainController: Not the time to replay command");
        }
        return;
    }
    DEBUG_LOG("TrainController: Replaying command type %d", cmd->type);
    if (!emergencyStop)
    {
        // Execute the command based on its type
        switch (cmd->type)
        {
        case CMD_MOTOR_SPEED:
            duploHub.setMotorSpeed(cmd->data.motor.speed);
            break;
        case CMD_STOP_MOTOR:
            duploHub.stopMotor();
            break;
        case CMD_SET_LED_COLOR:
            duploHub.setLedColor(cmd->data.led.color);
            break;
        case CMD_PLAY_SOUND:
            duploHub.playSound(cmd->data.sound.soundId);
            break;
        case CMD_SET_HUB_NAME:
            duploHub.setHubName(cmd->data.hubName.name);
            break;
        case CMD_ACTIVATE_RGB_LIGHT:
            duploHub.activateRgbLight();
            break;
        case CMD_ACTIVATE_BASE_SPEAKER:
            duploHub.activateBaseSpeaker();
            break;
        case CMD_ACTIVATE_COLOR_SENSOR:
            duploHub.activateColorSensor();
            break;
        case CMD_ACTIVATE_SPEED_SENSOR:
            duploHub.activateSpeedSensor();
            break;
        case CMD_ACTIVATE_VOLTAGE_SENSOR:
            duploHub.activateVoltageSensor();
            break;
        default:
            DEBUG_LOG("TrainController: Unknown command type %d in replay", cmd->type);
            break;
        }
        DEBUG_LOG("TrainController: Replayed command type %d", cmd->type);
    }
}
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
void loop()
{
    statusLed.update(); // Handle blinking

    // Check for idle time to enter deep sleep
    if(lastUserActionTime != 0 && (millis() - lastUserActionTime) > maxIdleTime)
    {
        esp_goto_sleep();
    }

 
    if (duploHub.isConnected())
    {
        guiButtons.updateButtons();

        // Handle replay commands if replay is active
        if (duploHub.isReplayActive())
        {
            replayNextCommand();
        }

         duploHub.processResponseQueue();
    }

    // Check Duplo Hub State
    checkStatus(duploHub);

    delay(20); // Add a small delay to reduce CPU load and prevent guru meditation error
} // End of loop

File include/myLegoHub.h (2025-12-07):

/**
 * @file myLegoHub.h
 * @brief Thin wrapper around `Lpf2Hub` adding DUPLO-specific helpers.
 *
 * Declares `myLegoHub`, a small extension of Legoino's base hub with convenience helpers for
 * activating DUPLO ports and parsing sensor data. `DuploHub` builds on this abstraction to offer
 * higher-level features.
 *
 * @author Ralf Zühlsdorff
 * @date 2025
 *
 * @copyright
 * MIT License
 */
#ifndef MY_LEGO_HUB_H
#define MY_LEGO_HUB_H

#include "Lpf2Hub.h"
#include "LegoinoCommon.h"

namespace DuploEnums
{
    // Device types for Duplo Train Hub
    enum struct DuploTrainDeviceType
    {
        DUPLO_TRAIN_BASE_MOTOR = 41,
        DUPLO_TRAIN_BASE_SPEAKER = 42,
        DUPLO_TRAIN_BASE_COLOR_SENSOR = 43,
        DUPLO_TRAIN_BASE_SPEEDOMETER = 44,
        VOLTAGE_SENSOR = 20,
        LIGHT = 8
    };

    // Port enumeration for Duplo Train Hub
    // These ports correspond to the physical ports on the DUPLO Train Hub
    // and are used for device activation and communication.
    enum struct DuploTrainHubPort
    {
        MOTOR = 0x00,
        LED = 0x11,
        SPEAKER = 0x01,
        COLOR = 0x12,
        SPEEDOMETER = 0x13,
        VOLTAGE = 0x14
    };

    

    // Enum for available Duplo sounds
    enum DuploSound
    {
        BRAKE = 3,
        STATION_DEPARTURE = 5,
        WATER_REFILL = 7,
        HORN = 9,
        STEAM = 10
    };

    // Enum for available Duplo colors
    enum DuploColor
    {
        BLACK = 0,
        PINK = 1,
        PURPLE = 2,
        BLUE = 3,
        LIGHT_BLUE = 4,
        CYAN = 5,
        GREEN = 6,
        YELLOW = 7,
        ORANGE = 8,
        RED = 9,
        WHITE = 10
    };

    
}

// Callback function types
typedef void (*ConnectionCallback)();

// Add a typedef for the detected color callback
typedef void (*DetectedColorCallback)(DuploEnums::DuploColor);

// Add a typedef for the speed callback
typedef void (*DetectedSpeedCallback)(int detectedSpeed);

// Add a typedef for the voltage callback
typedef void (*DetectedVoltageCallback)(float detectedVoltage);




// Class myLegoHub adds extensions and small modifucations to the Lpf2Hub class

class myLegoHub : public Lpf2Hub {
public:
    /** @brief Enable the DUPLO speaker port. */
    void activateBaseSpeaker();

    /** @brief Start playback of a DUPLO sound effect. */
    void playSound(byte sound);

    /** @brief Enable the on-hub RGB LED port. */
    void activateRgbLight();

    /** @brief Apply a color to the on-hub RGB LED. */
    void setLedColor(Color color);

    /** @brief Map the raw speedometer count into a normalized range. */
    int MapSpeedometer(int rawSpeed, int maxRawSpeed = 255);

    /** @brief Convert raw voltage sensor bytes into volts. */
    float parseVoltage(uint8_t *pData);
};

#endif // MY_LEGO_HUB_H

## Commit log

2025-07-20 feat: Implement multi-core architecture for DUPLO Train Controller
    - Add DuploHub class with thread-safe API and FreeRTOS integration
    - Implement BLE operations on dedicated task (Core 0)
    - Add command queue system for inter-task communication
    - Rename TrainHub.cpp to TrainController.cpp for semantic clarity
    - Add automatic connection recovery with background monitoring
    - Implement mutex-based synchronization for thread safety
    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
2025-07-20 feat: Add extended sensor support with bidirectional data processing
    - Implement DuploHubExtended class with sensor callback system
    - Add bidirectional FreeRTOS queues (commands + sensor data)
    - Create static callback wrappers for Lpf2Hub integration
    - Add TrainController_Extended.cpp with color-based speed control
    - Implement real-time sensor processing with ~75ms total latency
    - Add comprehensive sensor processing chain documentation
    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
2025-07-21 DuploHub and TrainController implemented with motor controll, color led control and sound control and succesfully implemented Fronend running on core 1 and BLE related backend task running on Core 0 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
    [DuploHub.cpp, DuploHub.h, SytemMemory.cpp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]
2025-07-21 documentation updated High delay between initalization of command and execution in lego device needs further investigation
2025-07-24 initiale Implementierung sensor Callback und response queue Test steht noch aus
2025-07-24 - debug log macros und functions generated - mutex print does not allways function - detection of colors with duplo base sensor seems to function, but has to be tested with different duplo color stic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
2025-07-27 intermediate version mit color und speed sensor fehler: kommandos werden nicht übertragen an device
2025-07-27 Sound, LED, Motor, Speed und Color callback ok Speed cb liefert Werte zwischen -255 und + 255, muss ggf in DuploHub angeüpasst werden auf Wertebereich der Motor Speed von -100 bis +100 Color Callback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
2025-07-27 Voltage callback ok, thresholds macros für speed und voltage callback execution eingeführt. Reconnect nach power cycle des Duplo Zuges funktioniert Nächste Schritte: Anbindung an das UI und Test mit 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
2025-07-29 Refactoring: - all test functions have been removed frome TrainController with exception of simple test for motor, sound and led - all not required calls to DuploHub have been removed - unnessesary c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
    [DuploTrainController.kicad_pcb, DuploTrainController.kicad_sch]
2025-07-30 Traincontroller Buttons are working after Logging was modified to log without semaphor
    [DuploTrainController.kicad_sch]
2025-07-30 Finale Version (Bis zum ersten Fehler): - alle Funktionstasten ok - Nothalt Taste schaltet den Motor aus und beim 2. TAstendruck läuft der Motor mit alter Richtung und Geschwindigkeit - Fahrregler ka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
2025-07-30 duplicated #ifndefs deleted Compiles now without error
    [myLegoHub.h]
2025-07-30 Readme und Architekturbeschreibung überarbeitet
2025-08-01 small changes
    [DuploTrainController NG.kicad_pcb, DuploTrainController NG.kicad_sch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]
2025-08-04 ADC Button Handler funktioniert mit den gesetzten Defaults
2025-08-05 Alle buttonfunktionen ok Record / Replay funktioniert gut, hier ggf. mal die Zeitabstände überprüfen eineg Klasse zur Ansteuerung der RGB LED erstmal nur für eine LED kann noch optimiert werden GAnze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
    [DuploTrainController NG.kicad_pcb, DuploTrainController NG.kicad_sch, DuploTrainController.kicad_pcb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]
2025-08-05 still timing issues when replaying
    [DuploHub.cpp, DuploHub.h, TrainController.cpp]
2025-08-17 Replay wird nur noch einmal ausgeführt
2025-08-17 Blockiern aller Kommandos außer Stop und Replay (zum Beenden des Replay Modus) funktioniert. Stop und Replay beenden sofort das Replay.
2025-08-17 blockierung der Color Sensor Aktionen im Replay Modus ist implementiert. Im Recoord modus werden die durch den Color Sensor identifizierten Aktionen aufgezeichent
2025-08-17 Status LED funktioniert wie festgelegt bis auf Reaktion auf niedrigen Batterie Level
2025-08-17 Voltage Sensor und Batteriewarnung funktioniert. Alle Statusänderungen werden über LED richtig angezeigt
2025-08-17 Für produktiven Einsatz muss DEBUG ausgeschaltet sein, da sonst die MCU ständig rebootet
    [TrainController.cpp]
2025-12-05 ZUsätzliche Buttons und Encoder Button funtionieren. Speed handling angepasst und Speed callback aktiviert Probleme bei - ColorCB liefert keine stabilen Werte - init mit Hub Mac Adresse funktioniert 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
    [ADCButton.cpp, TrainController.cpp]
2025-12-07 Debeouncing of Color Sensor is now ok, but didi not always detect all colors (e.g. blue is detected as green, green is detected correct) Meeds to be check in detail how the mapping with the real Dupl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
    [DuploHub.cpp, DuploHub.h, TrainController.cpp]
2025-12-07 ESP deep sleep and wake up working. Controller goes to sleep after 5 minutes of in activity after first connect. Wakeup with encoder button press. Duplo train connects again and registers all sensor 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
2025-12-07 Corrected a small problem as the system restarted immediatly after going to sleep due to the fact that in sleep mode the encoder button pin was not held high. CAll to rtc_gpio_pullup_en () kept the e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
    Updated documentation in readme and architecture document.
    [DuploHub.cpp, DuploHub.h, SytemMemory.cpp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]
2025-12-07 Added board design as KiCAD files in hardware directory
2025-12-09 Added SCAD files for case and updated documentation
2025-12-09 Add enclosure assets and update docs
    [Controller.3mf, Controller.scad]
2025-12-09 Add all hardware/DuploTrainController NG files as regular files, remove submodule link
    [5 Buttons an ADC.xlsx, DuploTrainController NG.kicad_pcb, DuploTrainController NG.kicad_sch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]
